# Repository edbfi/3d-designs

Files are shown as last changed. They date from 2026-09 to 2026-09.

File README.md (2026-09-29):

# 3d-designs

My parametric 3D-print designs. Each one is an OpenSCAD source you can customise, plus ready-to-print Bambu Studio projects.

## Designs

| Design | What it is | Path |
|---|---|---|
| Netflix-style lettering | `NETFLIX` and `SERIER` in Netflix-style bent lettering for a school library display: a stand, a plaque and loose wall letters. Built for the Bambu Lab A1 mini (with or without AMS lite) and A2L Combo | [`netflix-lettering`](netflix-lettering) |

## Layout

Every design has its own folder:

```
<design>/
├── README.md            # what it is, which file to print, how to customise
├── <design>.scad        # the parametric source (OpenSCAD Customizer)
├── fonts/               # bundled fonts with their licences, if any
├── print-files/         # ready-to-print Bambu Studio projects, one folder per printer setup
├── templates/           # paper templates, if any
├── docs/                # design notes, build summary, images
└── tools/               # the script that regenerates print-files/ and docs/
```

## Licence

[AGPL-3.0](LICENSE), except bundled fonts, which keep their own licence (see each design's `fonts/`).

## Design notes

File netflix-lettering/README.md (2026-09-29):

# Netflix-style lettering

Two exhibition pieces for a school library, `NETFLIX` and `SERIER`, in Netflix-style bent lettering. Each comes in three designs, and every file is ready to print on a Bambu Lab A1 mini (with or without an AMS lite) or an A2L Combo. Everything is parametric, so a new word, font or size is one setting away.

| | NETFLIX | SERIER |
|---|---|---|
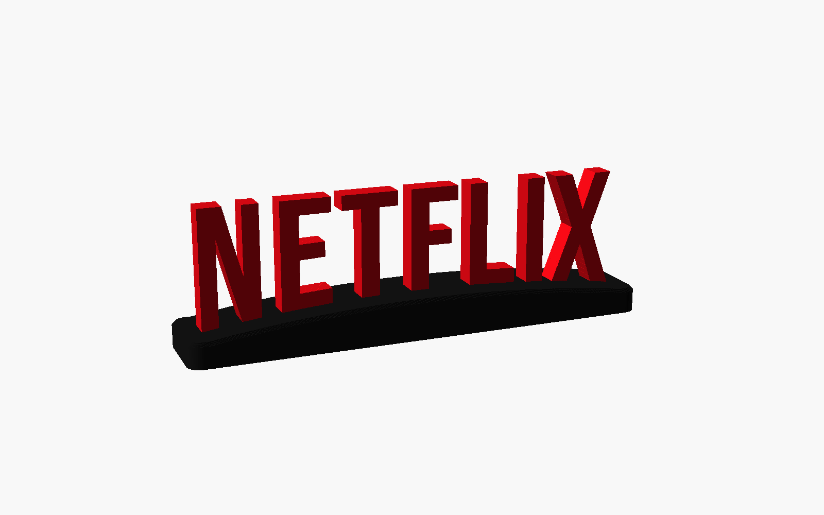
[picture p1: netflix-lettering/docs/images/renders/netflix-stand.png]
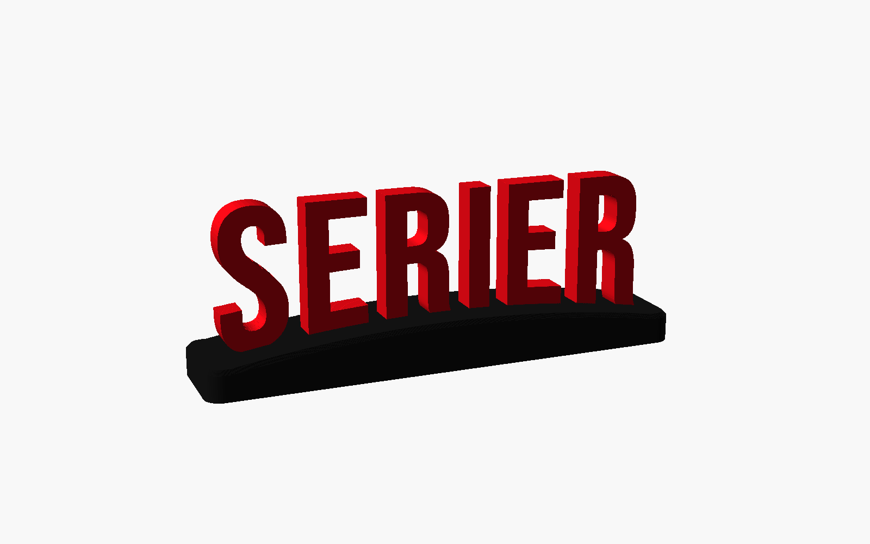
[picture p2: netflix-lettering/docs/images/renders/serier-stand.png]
| **Stand**: red letters on a black plinth that follows the arc |  |  |
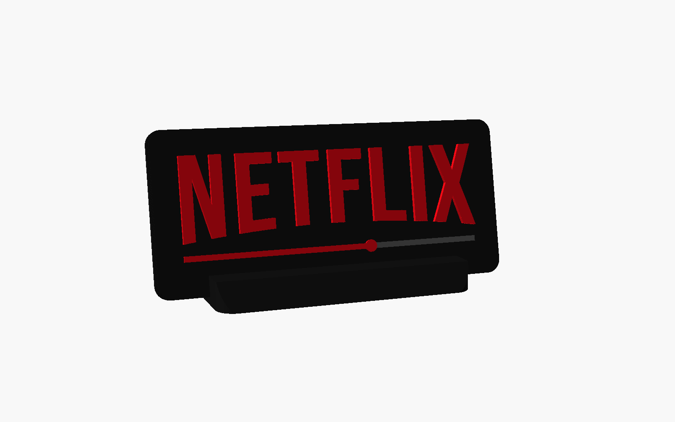
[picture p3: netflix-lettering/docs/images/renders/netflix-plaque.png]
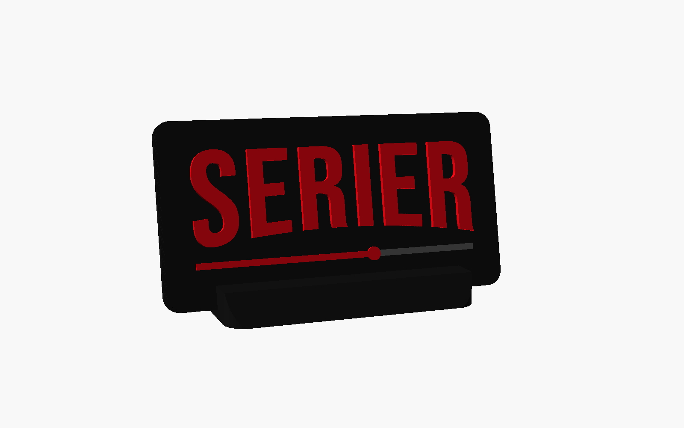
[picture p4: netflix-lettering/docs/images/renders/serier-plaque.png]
| **Plaque**: black screen with raised letters and a Netflix progress bar, in a leaning stand |  |  |
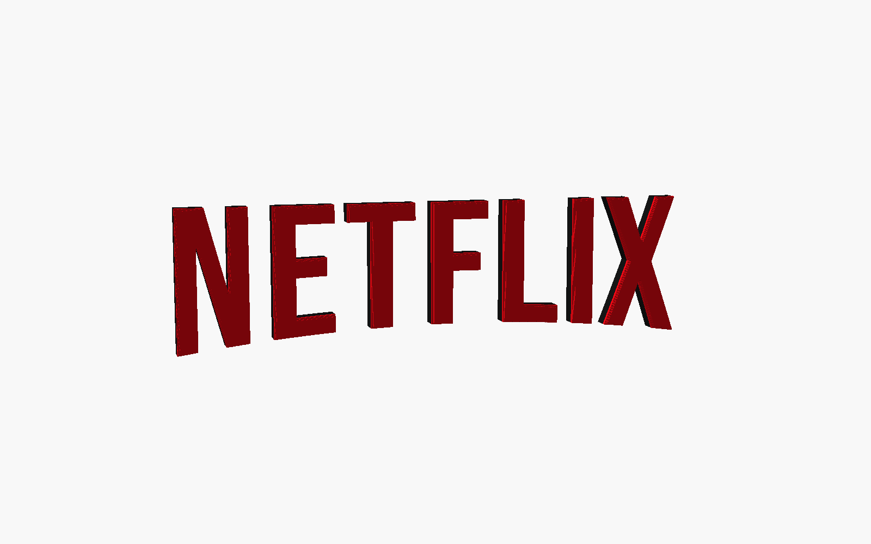
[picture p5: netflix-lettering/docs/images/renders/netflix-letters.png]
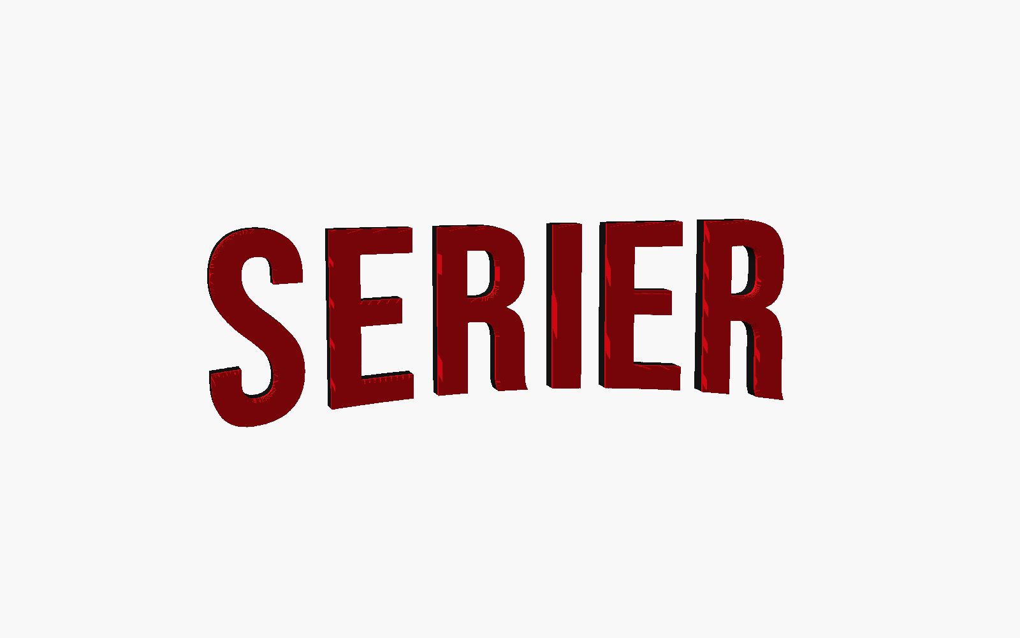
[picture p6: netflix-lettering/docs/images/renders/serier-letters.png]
| **Loose letters**: chunky two-tone letters for a wall or pinboard |  |  |

## Pick a file

Open the `.3mf` in Bambu Studio. The printer, plates, filaments, colours and any filament-swap pauses are already set, and every plate is sliced. For the plates, times and grams of each file, see [`docs/build-summary.md`](docs/build-summary.md).

The files come in three sets, each with all three designs:

- **`single-colour/`**: no AMS; every plate prints in one colour. The colours come from separate parts that go together afterwards. This is the simplest option for the two A1 minis.
- **`colour-swap/`**: no AMS; some plates pause once so you can swap black for red by hand, which gives two-tone parts from one plate.
- **`ams/`**: the AMS lite switches colours by itself, on the A1 mini with an AMS lite or on the A2L Combo (bigger versions).

| Design | Single colour (A1 mini) | Colour swap (A1 mini) | AMS (A1 mini + AMS lite) | AMS (A2L Combo) |
|---|---|---|---|---|
| Stand | [netflix](print-files/single-colour/a1-mini/netflix-stand-single-colour-a1-mini.3mf) · [serier](print-files/single-colour/a1-mini/serier-stand-single-colour-a1-mini.3mf) | [netflix](print-files/colour-swap/a1-mini/netflix-stand-colour-swap-a1-mini.3mf) · [serier](print-files/colour-swap/a1-mini/serier-stand-colour-swap-a1-mini.3mf) | [netflix](print-files/ams/a1-mini/netflix-stand-ams-a1-mini.3mf) · [serier](print-files/ams/a1-mini/serier-stand-ams-a1-mini.3mf) | [netflix](print-files/ams/a2l-combo/netflix-stand-ams-a2l-combo.3mf) · [serier](print-files/ams/a2l-combo/serier-stand-ams-a2l-combo.3mf) |
| Plaque | [netflix](print-files/single-colour/a1-mini/netflix-plaque-single-colour-a1-mini.3mf) · [serier](print-files/single-colour/a1-mini/serier-plaque-single-colour-a1-mini.3mf) | [netflix](print-files/colour-swap/a1-mini/netflix-plaque-colour-swap-a1-mini.3mf) · [serier](print-files/colour-swap/a1-mini/serier-plaque-colour-swap-a1-mini.3mf) | [netflix](print-files/ams/a1-mini/netflix-plaque-ams-a1-mini.3mf) · [serier](print-files/ams/a1-mini/serier-plaque-ams-a1-mini.3mf) | [netflix](print-files/ams/a2l-combo/netflix-plaque-ams-a2l-combo.3mf) · [serier](print-files/ams/a2l-combo/serier-plaque-ams-a2l-combo.3mf) |
| Loose letters | [netflix](print-files/single-colour/a1-mini/netflix-letters-single-colour-a1-mini.3mf) · [serier](print-files/single-colour/a1-mini/serier-letters-single-colour-a1-mini.3mf) | [netflix](print-files/colour-swap/a1-mini/netflix-letters-colour-swap-a1-mini.3mf) · [serier](print-files/colour-swap/a1-mini/serier-letters-colour-swap-a1-mini.3mf) | [netflix](print-files/ams/a1-mini/netflix-letters-ams-a1-mini.3mf) · [serier](print-files/ams/a1-mini/serier-letters-ams-a1-mini.3mf) | [netflix](print-files/ams/a2l-combo/netflix-letters-ams-a2l-combo.3mf) · [serier](print-files/ams/a2l-combo/serier-letters-ams-a2l-combo.3mf) |

Finished sizes (NETFLIX; SERIER is about 15 % narrower):

| Design | A1 mini files | A2L Combo files |
|---|---|---|
| Stand | 167 × 30 mm plinth, 42 mm letters, 51 mm tall | 301 × 50 mm plinth, 76 mm letters, 90 mm tall |
| Plaque | 155 × 69 mm, 36 mm letters | 295 × 126 mm, 70 mm letters |
| Loose letters | 75 mm tall, 294 mm wide on the wall | 120 mm tall, 458 mm wide on the wall |

All files use Bambu PLA Matte, the 0.20 mm Standard profile and the textured PEI plate. Any PLA works; pick a strong red (Netflix red is `#E50914`) and a black or charcoal.

## Printing and assembly

Every no-AMS project has two plates, so both A1 minis can run at once: in Bambu Studio, send plate 1 to one printer and plate 2 to the other. With one printer, print them one after the other.

### Single colour (no AMS)

- **Stand**: plate 1 is the letters, in red, printed face down so the textured plate gives them a crisp front. Plate 2 is the plinth, in black. Push each letter's tab into its pocket; it's a press fit with 0.15 mm clearance per side, and a drop of glue makes it permanent. About 50 min per printer.
- **Plaque**: plate 1 is the red letters and the progress bar's fill as separate pieces, printed face down (about 17 min). Plate 2 is the black plaque with matching pockets, and its stand. Press each red piece into its pocket (0.15 mm clearance; glue optional), then slide the plaque into the stand's leaning slot.
- **Loose letters**: all red, split over two plates.

### Colour swap (no AMS, one manual swap per plate)

- **Stand**: the same two plates as the single-colour set. Change the spool between plates rather than mid-print: the arched plinth has no single layer where black could end, so a one-piece swap isn't possible.
- **Plaque**: plate 1 starts in black and **pauses at 4.2 mm**. On the printer, unload black, load red and resume. The letters and the filled part of the bar come out red; the rest of the bar stays a black groove. Plate 2 is the black stand.
- **Loose letters**: both plates start in black and **pause at 7.2 mm**. Swap to red and resume, which gives black letters with a red face.

### AMS (A1 mini + AMS lite, or the A2L Combo)

One plate, no manual swaps. Load red in the slot for filament 1 and black for filament 2. The plaque also uses grey as filament 3, for the bar's track.

- **Stand**: prints upright in one piece, running along the bed's Y axis so the thin letters are stiff against the moving bed. Bambu's tree supports hold up the arms of E, F and T and snap off their hidden undersides. The model can build [support-fin](https://printfins.com/)-style breakaway fins instead (`stand_fins = true`). Bambu Studio flags model-built supports as a floating cantilever, though, so the files use its own supports.
- **Plaque**: the plaque and its stand print together.
- **Loose letters**: black body with a red face. The AMS changes colour once per plate.

### Hanging the loose letters

Print the matching template from [`templates/`](templates) at 100 % scale (no "fit to page"). The A1 mini ones need A3, or A4 tiled; the A2L ones need tiling. Tape it to the wall, then place each letter on its outline. The line above the letters is the flat top edge; keep it level. Double-sided foam tape or poster putty holds the letters well. The model can also add a back recess for tape or magnet sheet (`letters_mount = "recess"`).

## Customise

Open `netflix-lettering.scad` in [OpenSCAD](https://openscad.org) and show **Window → Customizer**. The main settings:

| Setting | What it does |
|---|---|
| `text_string` | The text. Lowercase is turned into capitals (`force_caps`), and spaces and Norwegian letters work |
| `font_name` | Bebas Neue (default, closest to Netflix), Anton (heavier), League Gothic (narrower), or any installed font |
| `letter_height` | Height of the outer letters in mm; the width follows from the text |
| `arc_depth` | How much shorter the middle letters are (0 = straight, 0.134 = Netflix logo) |
| `letter_spacing`, `stroke_weight` | Tighter or looser spacing; bolder or thinner strokes |
| `design` | `stand`, `plaque` or `letters` |
| `part` | `display` for the coloured preview; the other values output one print part laid out for printing |

Each design has its own group of settings: plinth size, chamfers, letter depth, plaque margins, progress-bar fill, stand tilt, mounting recess and so on. Every setting has a comment in the file.

A full render takes 5–20 s.

To get your own text into Bambu Studio, you have two options:

- **One part at a time**: set `part` (for example `letters` and then `base` for the stand), press F6 and export each as STL.
- **Whole projects**: edit `TEXTS` (and `SIZES` if needed) at the top of [`tools/build.py`](tools/build.py) and run it (see below). You get the same ready-to-print projects as here, for every printer setup.

On **MakerWorld's Parametric Model Maker**, use [`makerworld/netflix-lettering-makerworld.scad`](makerworld/netflix-lettering-makerworld.scad), not the desktop file. It's generated from the desktop file and tested on MakerWorld.

- **Plates:** its 3MF has two plates, one per printer, in the right colours: stand letters and plinth, plaque and its stand, or the loose letters split in two. Set `makerworld_stand = "one piece"` for the upright AMS stand.
- **Fonts:** you get MakerWorld's font picker with 500+ Google Fonts; Bebas Neue is among them.
- **Before printing a MakerWorld 3MF:** switch the plate type to **Textured PEI Plate** in Bambu Studio. MakerWorld defaults to Cool Plate, which heats the bed to only 35 °C.
- **No pauses:** MakerWorld can't add filament-swap pauses, so the plaque and loose letters need an AMS for two colours. For the no-AMS two-colour versions, use the files in `print-files/`.

The desktop file uses no experimental OpenSCAD features, so it runs in the stock Customizer too.

## Rebuilding the print files

```bash
python3 tools/build.py                                   # everything, about 4 minutes
python3 tools/build.py --only serier --only 'a1-mini$'   # a subset
python3 tools/build.py --list                            # all variant keys
```

Needs OpenSCAD (a 2025+ snapshot with the Manifold backend is much faster than 2021.01) and Bambu Studio in `/Applications` (tested with 02.08.02.61). For every variant the script:

1. exports the parts,
2. lays out the plates,
3. builds the project with Bambu Studio's CLI and adds the pauses,
4. slices every plate with the stock Bambu profiles.

It refuses to write a project unless all of these hold:

- no stray mesh slivers,
- the real printer start G-code is present,
- each plate uses the right filament,
- pauses are at the exact layer.

Plate previews, the build summary, templates and renders in `docs/` are regenerated too.

## How the Netflix look is made

The Netflix wordmark is custom lettering, and Netflix Sans isn't free. So this uses **Bebas Neue**, a free font (SIL OFL) whose letter widths match the logo's within about 2 % of the letter height. It is then bent like the logo:

- the top edge stays flat;
- the bottom edge follows a parabola, so the middle letters are 13.4 % shorter than the outer ones.

Those numbers, and letter spacing 1.08, were measured and fitted against the real logo. For the measurements, the font comparison and the geometry tricks that keep the model customisable without experimental OpenSCAD features, see [`docs/design-notes.md`](docs/design-notes.md).

## Files

```
netflix-lettering/
├── netflix-lettering.scad      # the parametric model
├── fonts/                      # Bebas Neue, Anton, League Gothic + their OFL licences
├── print-files/
│   ├── single-colour/a1-mini/  # no AMS, one colour per plate, parts go together
│   ├── colour-swap/a1-mini/    # no AMS, a pause for a manual filament swap
│   └── ams/                    # AMS lite: a1-mini/ and a2l-combo/ (bigger versions)
├── makerworld/                 # MakerWorld Parametric Model Maker edition (generated)
├── templates/                  # 1:1 wall templates for the loose letters (SVG)
├── docs/
│   ├── design-notes.md         # research, measurements, techniques
│   ├── build-summary.md        # every project: plates, times, grams (generated)
│   └── images/                 # renders and Bambu plate previews (generated)
└── tools/build.py              # regenerates print-files/, templates/ and docs/
```

## Licence and trademarks

The model, build script and print files are [AGPL-3.0](../LICENSE). The MakerWorld listing ("Streaming-style bent lettering (customizable)", a draft for now) offers the MakerWorld edition under [CC BY-SA 4.0](https://creativecommons.org/licenses/by-sa/4.0/), the closest Creative Commons match to the AGPL's share-alike terms. The fonts in `fonts/` are under the SIL Open Font License 1.1 and belong to their authors (see the `OFL-*.txt` files).

Netflix is a trademark of Netflix, Inc. This is an independent, fan-made lookalike for a school library display. It is not affiliated with or endorsed by Netflix, and it contains no Netflix artwork: the lettering is a free font bent to a similar shape.

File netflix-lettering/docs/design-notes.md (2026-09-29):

# Design notes

How the Netflix look was measured and rebuilt, and the techniques that keep the model fully parametric in plain OpenSCAD.

## Measuring the Netflix wordmark

The 2015 Netflix wordmark (the Wikimedia Commons SVG, used only as a local reference and not included in this repo) was rasterised and measured column by column:

| Property | Netflix logo |
|---|---|
| Top edge | Flat: every letter starts at the same line |
| Bottom edge | Arc, lowest at the outer letters and highest in the middle |
| Middle letters vs. outer letters | 13.4 % shorter |
| Arc shape | A parabola: at 10/20/30/40 % across, the bottom sits at 0.951/0.915/0.888/0.874 of the full height; a parabola with depth 0.134 gives 0.952/0.914/0.887/0.873 |
| Word width | 3.70 × the outer letter height |
| Stem width | 0.15–0.17 × letter height |
| Letter widths (× height) | N 0.51, E 0.43, T 0.48, F 0.44, L 0.42, I 0.15, X 0.57 |
| Gap between letters | About 0.10 × height |

The top edge is flat and only the bottom curves. That is what makes it read as "Netflix", and a first attempt that curved both edges looked wrong.

## Choosing the font

The Netflix lettering is custom, and Netflix Sans is proprietary. Free condensed fonts, measured with OpenSCAD's `textmetrics` (widths as a fraction of cap height):

| Font | Stem | N | E | T | F | L | I | X | Word (spacing 1) |
|---|---|---|---|---|---|---|---|---|---|
| **Netflix logo** | 0.15–0.17 | 0.51 | 0.43 | 0.48 | 0.44 | 0.42 | 0.15 | 0.57 | 3.70 |
| **Bebas Neue** | 0.16 | 0.49 | 0.43 | 0.49 | 0.42 | 0.42 | 0.16 | 0.55 | 3.41 |
| Anton | 0.19 | 0.49 | 0.41 | 0.44 | 0.40 | 0.41 | 0.19 | 0.53 | 3.21 |
| League Gothic | 0.15 | 0.43 | 0.34 | 0.42 | 0.35 | 0.34 | 0.15 | 0.47 | 2.93 |

Bebas Neue matches every letter within about 0.02 of the letter height. The only real difference is spacing. Sweeping `letter_spacing`, `arc_depth` and `stroke_weight` against the rasterised logo (overlap measured as intersection over union) gave the defaults:

| letter_spacing | 1.00 | 1.04 | 1.06 | **1.08** | 1.10 | 1.12 |
|---|---|---|---|---|---|---|
| overlap with the logo | 0.41 | 0.52 | 0.69 | **0.83** | 0.73 | 0.55 |

`arc_depth` 0.134 (the measured value) scored best. Any extra stroke weight made it worse. The rest of the gap to a perfect overlap comes from the logo's custom N and X diagonals.

## Bending text in plain OpenSCAD

OpenSCAD can't warp geometry, so `warp2d` cuts the word into vertical strips and scales each one vertically about the top edge, by `1 − arc_depth · (1 − u²)` (u = −1…1 across the word). Neighbouring strips abut exactly. The number of strips follows from the letter height and arc depth, so the step between two strips along the bottom edge stays around `bend_step` = 0.1 mm, well below what a 0.4 mm nozzle can show. That's about 240 strips for 42 mm letters and the 800-strip cap at 120 mm. Straight text (`arc_depth` = 0) isn't cut at all.

Everything else that has to meet the lettering is bent with the same strips, so the surfaces match to within 0.01 mm:

- the plinth's arched top,
- the region under the arc used for tabs and pockets.

The arc is anchored to the text's **baseline**, not its lowest point. Round letters (S, O) dip slightly below the baseline, and anchoring to them would leave the flat letters floating above the plinth. The dip is trimmed from the one-piece letters so the two colours never overlap in the slicer.

## Parametric without measuring text

A MakerWorld-style model must react to any text, font and size, but `textmetrics` is experimental: it's off by default, and MakerWorld can't be relied on to have it. So the `.scad` never measures the text numerically. Instead:

- **Bounding boxes** come from hulls of copies pushed ±10 km along one axis (`bbox2d`, `xband2d`).
- **Normalising width**: the word is resized to exactly 100 units wide so the bend's u-coordinate is known. Sub-shapes (such as one letter's column) ride along with a far-away copy of the whole word's box, so they get the word's scale factor, not their own (`to_norm`).
- **Final size**: a box three times the letter height rides along 2000 units to the right, so every shape gets the letters' scale. It's then cut off again (`to_final`).
- **Centring**: the font's side bearings would push the word off-centre and make the arc lopsided. A Minkowski sum with a tiny square at minus the ink centre fixes that. The square is built from the ink box's corners scaled by −½ (`centre_shift2d`).
- **Proportional positions**: the progress bar's fill end is the word's right edge scaled by `2f − 1`.
- **Cleanup**: a morphological opening (`offset(r = 0.02) offset(r = −0.02)`) drops scraps thinner than 0.04 mm that coincident edges can leave. The stepped chamfers use round-join insets, because mitred insets turn microscopic notches into long spikes.

The bend instantiates its child once per strip, so that child is kept tiny (bare text or a box). An early version that passed richer subtrees through it took 1 min 40 s per render.

Three more habits keep a full render at 0.3–2 s (stand 1.3 s, plaque 0.3 s, loose letters 2.1 s at 42 mm):

- Offsets use bevelled joins (`chamfer = true`). Round joins put an arc on every strip corner.
- The word's x-range comes from the unbent box, because the bend only moves points vertically.
- The loose-letters preview extrudes the whole word at once instead of letter by letter.

## MakerWorld's Parametric Model Maker

Tested on MakerWorld with the logged-in account (unpublished):

- **Backend:** MakerWorld runs OpenSCAD with the Manifold backend and a render limit of about 10 s. The first upload timed out at 11 s local render time; after the speedups above it generates in about 13–20 s wall-clock, including MakerWorld's own overhead.
- **Plates:** MakerWorld builds a multi-plate, multi-colour 3MF from `mw_plate_N()` modules and `color()`, and previews `mw_assembly_view()`. It also adds any top-level geometry to every plate. So `tools/build.py` generates `makerworld/netflix-lettering-makerworld.scad` with the desktop output switched off. That edition also drops the local font includes, marks `font_name` with `// font` (MakerWorld's picker of 500+ Google Fonts; Bebas Neue is among them) and hides the desktop-only settings. The build checks that the edition has no top-level geometry and that every plate renders.
- **What its 3MF gets right:** the downloaded stand project has two plates, the red letters on filament 1 and the black plinth on filament 2. It carries the fully resolved A1 mini profile: real start G-code, 0.20 mm Standard, PLA Basic. Sliced, it takes 38 + 45 min, the same as our own files.
- **What it gets wrong:** the bed type is Cool Plate, so the bed heats to 35 °C, and supports are on (no supports actually get generated for these parts). Change the plate type to Textured PEI Plate in Bambu Studio before printing. MakerWorld can only preset profile options from a model's upload/edit page.
- **What it can't do:** there are no filament-swap pauses, so the no-AMS plaque and loose letters come out single-colour unless you print on an AMS printer or add the pause in Bambu Studio yourself. Multi-plate scripts can't offer STL download.

## Printability decisions

- **Stand, two-part (no AMS)**: letters print face down, so the textured PEI plate gives the visible face. Tabs follow each letter's bent bottom edge into matching pockets, with 0.15 mm clearance per side (0.146 mm measured).
- **Stand, one piece (AMS)**: letters print upright. The horizontal arms of E, F and T overhang 7–13 mm, so the project turns on tree supports. The word is turned to run along Y: on a bed-slinger, the thin letters then see the bed's motion along their stiff direction.
- **Breakaway fins (option)**: `stand_fins` builds supports into the model, in the spirit of [Support Fins](https://printfins.com/). printfins.com itself is a browser tool with manual orientation and no command-line interface, so the build can't call it.
  - *Where fins go:* a 1 mm skin is taken under every downward-facing edge and opened with r = 0.35 mm, which keeps only the overhangs flatter than 45°.
  - *Shape:* the region under those overhangs becomes twin 0.8 mm walls with one-layer rungs every 5 mm. They stand on the plinth or on a lower arm and stop 0.25 mm short of the letters, above and beside.
  - *Why off by default:* Bambu Studio can't see model-built supports and reports a "floating cantilever", while its own tree supports are warning-free here. The build fails on either warning, so the files use tree supports.
- **Three print-file sets**: `ams` (the AMS switches colours), `single-colour` (one colour per plate; colours come from separate parts) and `colour-swap` (a pause for a hand swap).
  - *Stand:* the arched plinth has no single layer where black could end, so the stand can't be swapped mid-print. Its colour-swap version is the two-part stand, with the spool changed between plates.
- **Plaque (single colour)**: the red letters and bar fill print face down as separate pieces. They press into 1.2 mm pockets in the black plaque, with 0.15 mm clearance per side. The pockets leave 2.8 mm of plaque below; the pieces stand 2 mm (letters) and 1 mm (bar) proud, like the other versions.
- **Plaque (colour swap)**: one filament swap. Black is used up to the plaque's top face (4.0 mm), and a pause runs at the start of the 4.2 mm layer. The progress bar's track is a groove in the plaque; the red fill and scrubber dot rise out of it, so the no-AMS version still reads as a two-colour bar.
- **Loose letters**: printed face up, with a 45° chamfer drawn in 0.2 mm steps (one per layer). The face is the top 3 mm, so a two-tone print needs only one colour change per plate. Letters are split over two plates by width, so two printers share the work.
- **Plate layout**: AMS plates keep a 45 × 55 mm corner free for the prime tower.

## Verification

Checked for these designs:

- **Overlap with the Netflix logo**: 83 % (above).
- **One-piece contact**: letters meet the plinth with 0.008 mm³ of overlap. Vertical rays through every letter run solid into the plinth.
- **Two-part fit**: letter tabs clear the plinth pockets by 0.146 mm.
- **Every build variant**:
  - no slivers in any part,
  - real Bambu start G-code (textured-plate bed temperature, A1 mini/A2L calibration routine),
  - each plate on the intended filament,
  - pauses exactly at the intended layer,
  - no slicer warnings.
- **Customisation stress test**: lowercase text, a space (`LES MER`), Norwegian `Ø`, Anton and League Gothic, `arc_depth` 0 and 0.25, and letter heights from 36 to 120 mm.

## Known limits

- `letter_height` runs from the baseline to the top of the text, so a round top overshoot (S, O) counts in it. Flat-topped outer letters of a word that contains round letters are about 1.5 % shorter (0.6 mm at 42 mm).
- In the Customizer, check that the text fits your bed. The build script checks the fit and splits the loose letters over extra plates automatically.
- `Impact` is only there if it's installed on the computer (it is on macOS and Windows). On MakerWorld, stick to Google Fonts.
- The upright one-piece stand needs supports. For the cleanest letter faces on an AMS printer, you can still print the two-part A1 mini version.

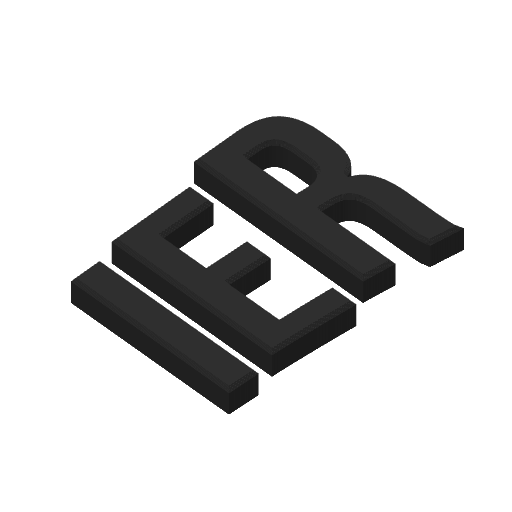
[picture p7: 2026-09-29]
netflix-lettering/docs/images/plates/serier-letters-colour-swap-a1-mini-plate-2.png

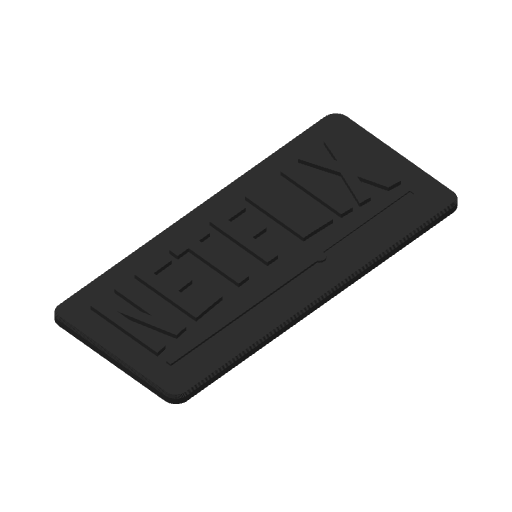
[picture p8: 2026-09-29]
netflix-lettering/docs/images/plates/netflix-plaque-colour-swap-a1-mini-plate-1.png

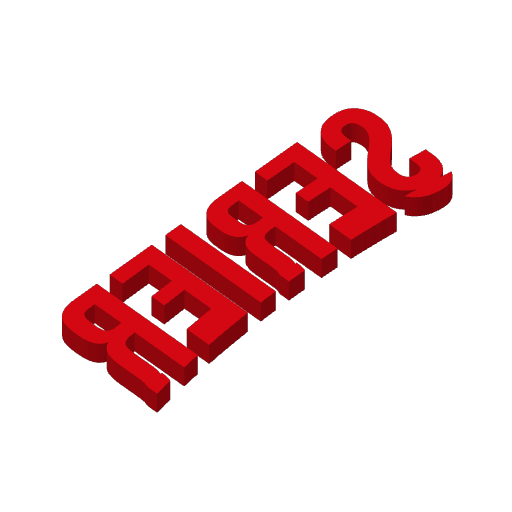
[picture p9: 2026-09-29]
netflix-lettering/docs/images/plates/serier-stand-single-colour-a1-mini-plate-1.png

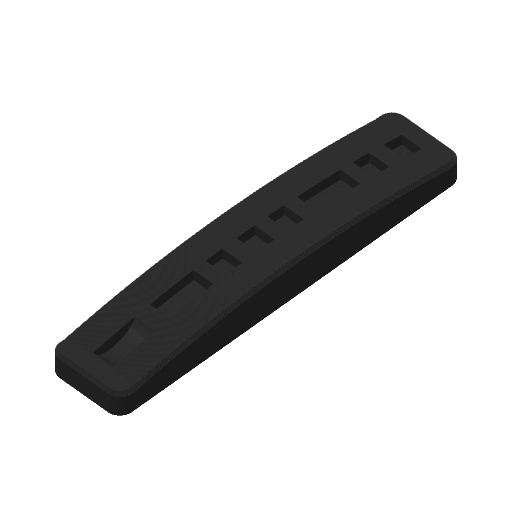
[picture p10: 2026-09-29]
netflix-lettering/docs/images/plates/serier-stand-colour-swap-a1-mini-plate-2.png

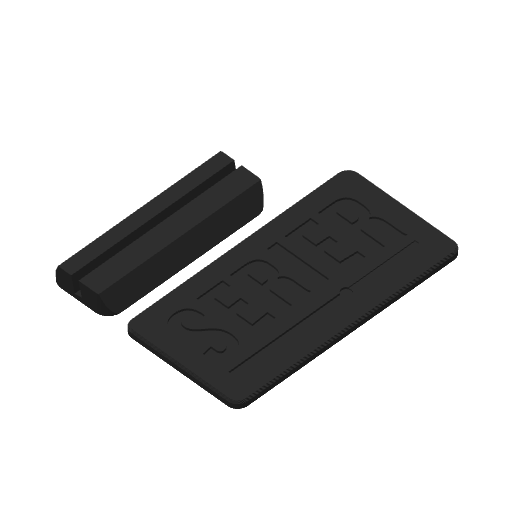
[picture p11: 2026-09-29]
netflix-lettering/docs/images/plates/serier-plaque-single-colour-a1-mini-plate-2.png

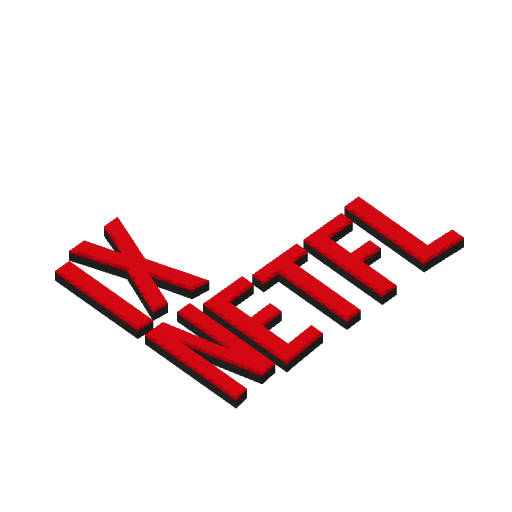
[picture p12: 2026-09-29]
netflix-lettering/docs/images/plates/netflix-letters-ams-a2l-combo-plate-1.png

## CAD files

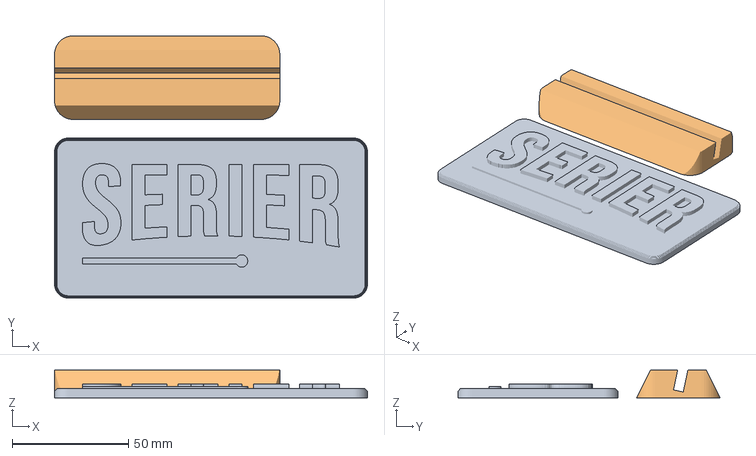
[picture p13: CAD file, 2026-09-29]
netflix-lettering/print-files/ams/a1-mini/serier-plaque-ams-a1-mini.3mf
134.9 x 113.0 x 12.0 mm
SERIER Plaque
SERIER Plaque stand

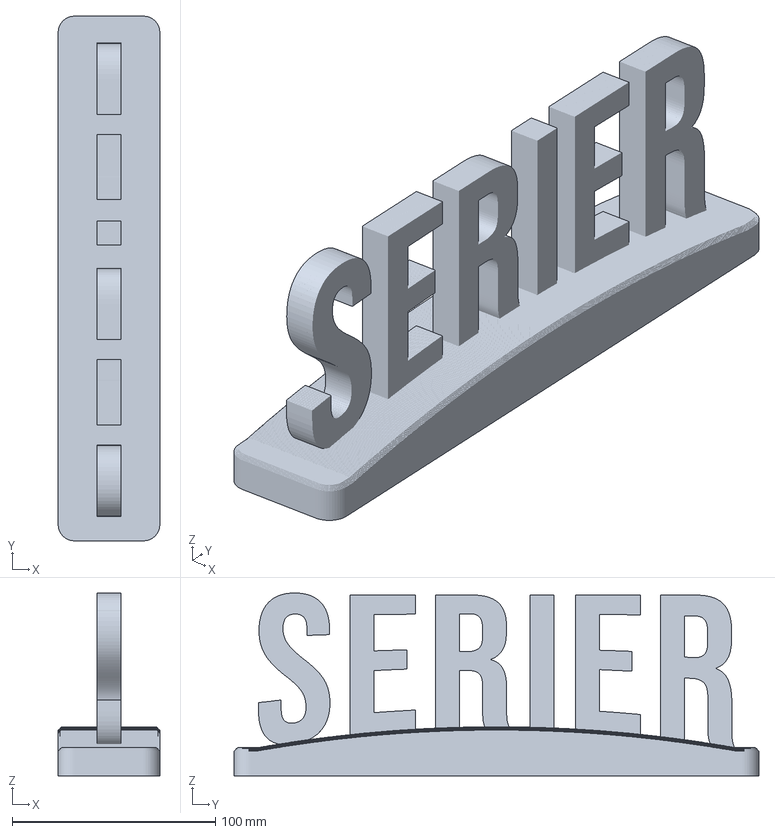
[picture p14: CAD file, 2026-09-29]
netflix-lettering/print-files/ams/a2l-combo/serier-stand-ams-a2l-combo.3mf
50.0 x 258.1 x 90.0 mm

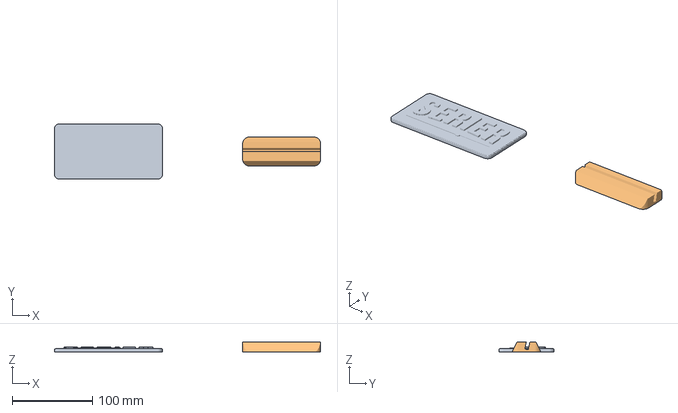
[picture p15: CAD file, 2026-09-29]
netflix-lettering/print-files/colour-swap/a1-mini/serier-plaque-colour-swap-a1-mini.3mf
332.0 x 69.0 x 12.0 mm
SERIER Plaque
SERIER Plaque stand

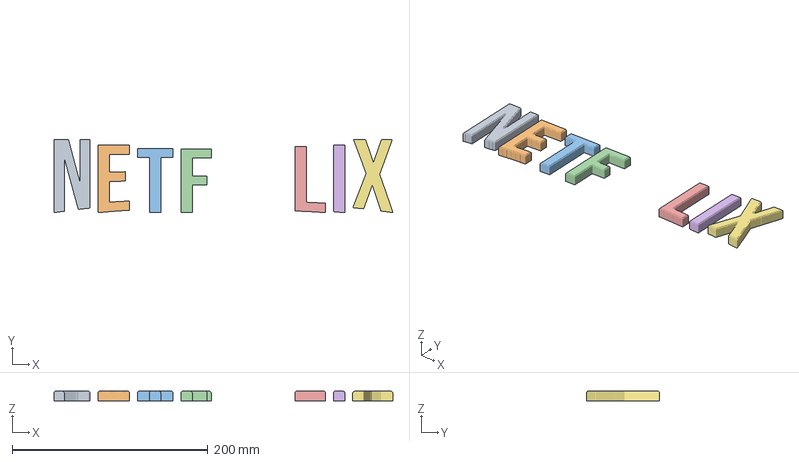
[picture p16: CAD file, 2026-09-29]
netflix-lettering/print-files/single-colour/a1-mini/netflix-letters-single-colour-a1-mini.3mf
346.5 x 75.0 x 10.0 mm
NETFLIX Letter 1 N
NETFLIX Letter 2 E
NETFLIX Letter 3 T
NETFLIX Letter 4 F
NETFLIX Letter 5 L
NETFLIX Letter 6 I
NETFLIX Letter 7 X

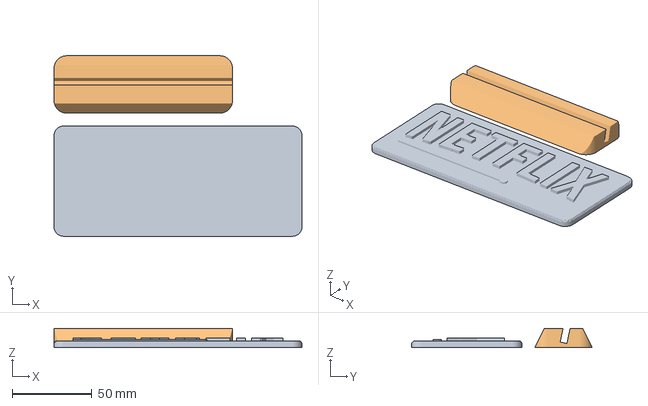
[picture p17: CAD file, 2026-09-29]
netflix-lettering/print-files/ams/a1-mini/netflix-plaque-ams-a1-mini.3mf
155.2 x 113.0 x 12.0 mm
NETFLIX Plaque
NETFLIX Plaque stand

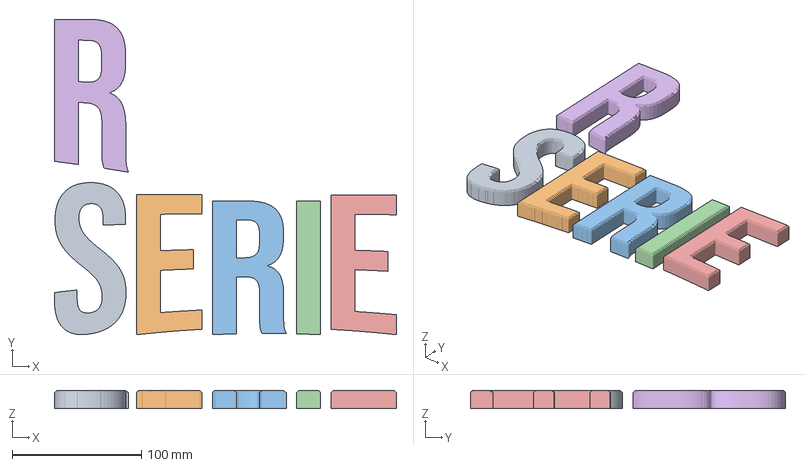
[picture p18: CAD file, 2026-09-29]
netflix-lettering/print-files/ams/a2l-combo/serier-letters-ams-a2l-combo.3mf
264.8 x 244.2 x 14.0 mm
SERIER Letter 1 S
SERIER Letter 2 E
SERIER Letter 3 R
SERIER Letter 4 I
SERIER Letter 5 E
SERIER Letter 6 R

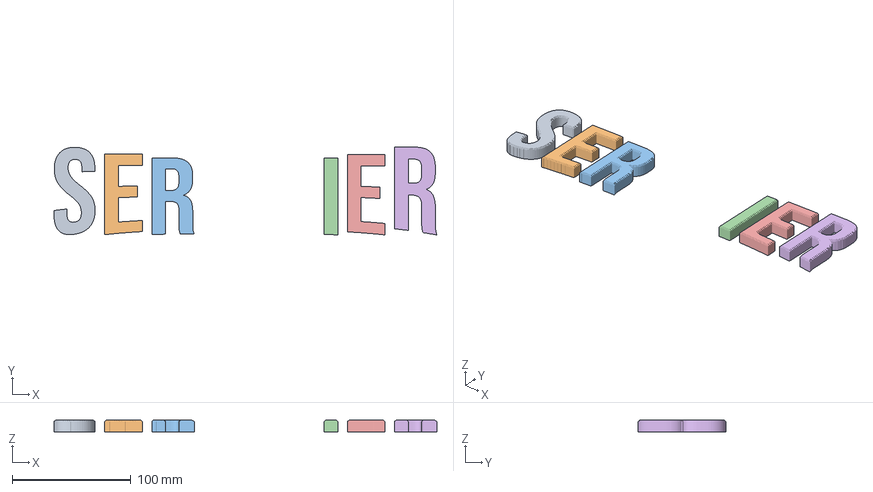
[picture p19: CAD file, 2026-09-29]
netflix-lettering/print-files/colour-swap/a1-mini/serier-letters-colour-swap-a1-mini.3mf
322.7 x 74.0 x 10.0 mm
SERIER Letter 1 S
SERIER Letter 2 E
SERIER Letter 3 R
SERIER Letter 4 I
SERIER Letter 5 E
SERIER Letter 6 R

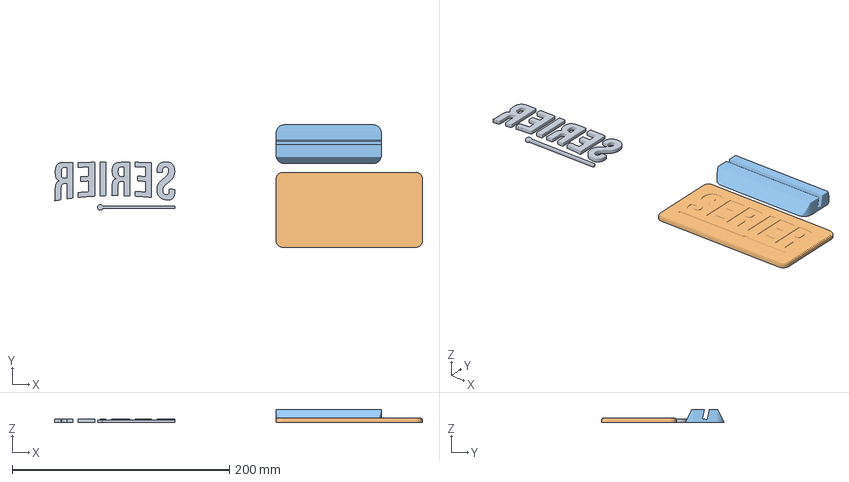
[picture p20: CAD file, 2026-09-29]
netflix-lettering/print-files/single-colour/a1-mini/serier-plaque-single-colour-a1-mini.3mf
338.9 x 113.0 x 12.0 mm
SERIER Red pieces
SERIER Plaque
SERIER Plaque stand

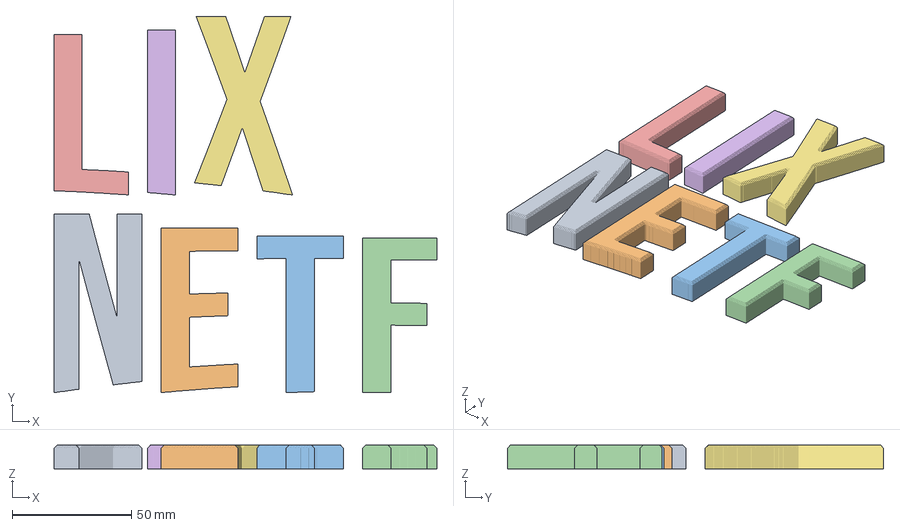
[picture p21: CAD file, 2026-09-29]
netflix-lettering/print-files/ams/a1-mini/netflix-letters-ams-a1-mini.3mf
160.8 x 158.0 x 10.0 mm
NETFLIX Letter 1 N
NETFLIX Letter 2 E
NETFLIX Letter 3 T
NETFLIX Letter 4 F
NETFLIX Letter 5 L
NETFLIX Letter 6 I
NETFLIX Letter 7 X

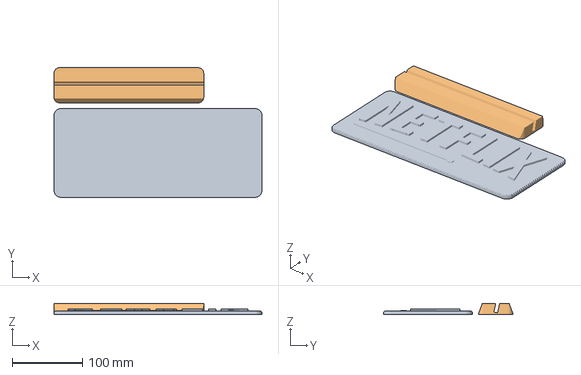
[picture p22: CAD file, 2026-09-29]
netflix-lettering/print-files/ams/a2l-combo/netflix-plaque-ams-a2l-combo.3mf
295.1 x 184.0 x 16.0 mm
NETFLIX Plaque
NETFLIX Plaque stand

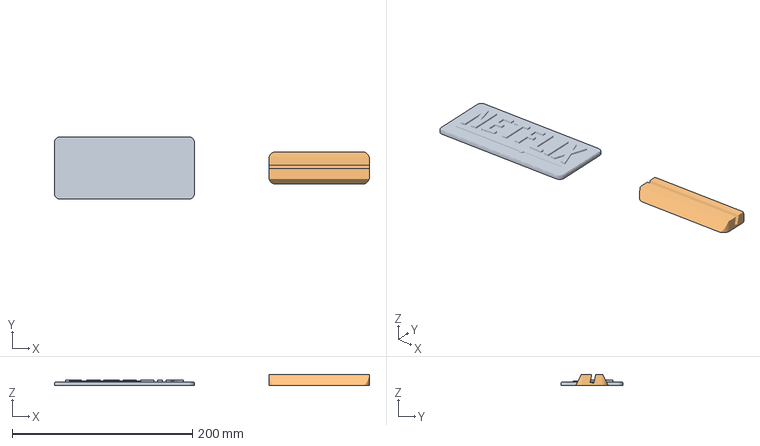
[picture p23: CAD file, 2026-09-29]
netflix-lettering/print-files/colour-swap/a1-mini/netflix-plaque-colour-swap-a1-mini.3mf
349.5 x 69.0 x 12.0 mm
NETFLIX Plaque
NETFLIX Plaque stand

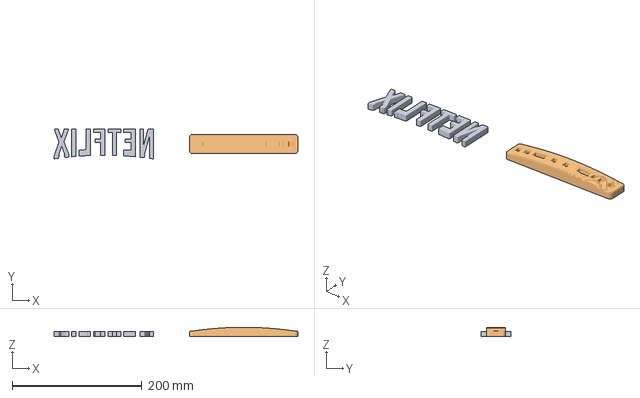
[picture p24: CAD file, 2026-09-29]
netflix-lettering/print-files/single-colour/a1-mini/netflix-stand-single-colour-a1-mini.3mf
376.1 x 46.0 x 14.6 mm
NETFLIX Letters
NETFLIX Plinth

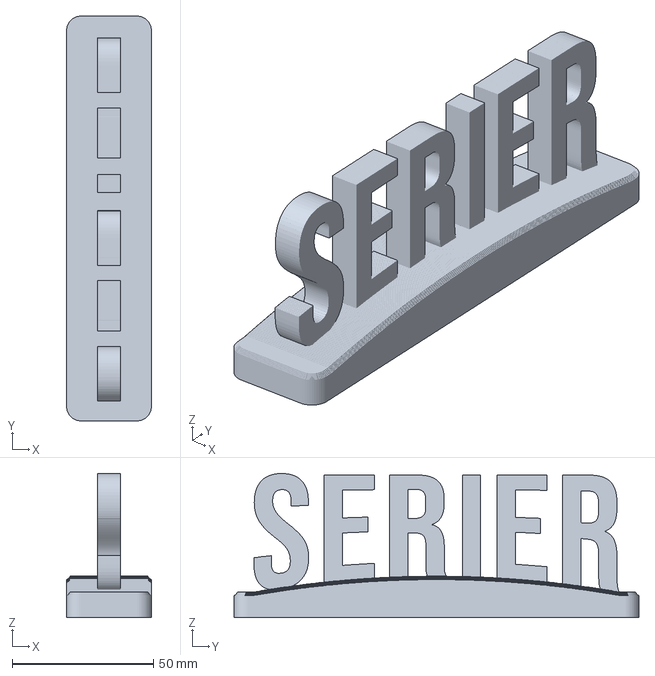
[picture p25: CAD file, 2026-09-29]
netflix-lettering/print-files/ams/a1-mini/serier-stand-ams-a1-mini.3mf
30.0 x 143.3 x 51.0 mm

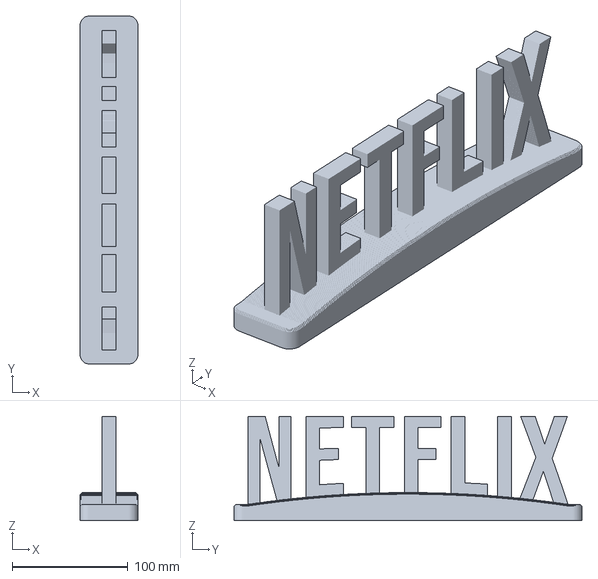
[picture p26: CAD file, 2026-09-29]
netflix-lettering/print-files/ams/a2l-combo/netflix-stand-ams-a2l-combo.3mf
50.0 x 301.0 x 90.0 mm

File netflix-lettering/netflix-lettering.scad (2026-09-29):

// Netflix-style lettering display (parametric, OpenSCAD Customizer / MakerWorld style)
//
// Three designs share one lettering core:
//   "stand"   red letters standing on a black plinth whose top follows the arc
//   "plaque"  black screen-style plaque, raised red letters, Netflix progress bar, ledge stand
//   "letters" loose chunky letters for a wall, pinboard or shelf
//
// Units mm, Z up. Display datum: centred in X and Y on the text, base at Z = 0.
// Print parts ("part" = anything except "display") sit on Z = 0 in print pose: flat,
// except the one-piece stand parts, which print upright as displayed.
//
// The lettering is a free font (Bebas Neue, SIL OFL) bent like the Netflix wordmark:
// flat top edge, bottom edge on a parabolic arc, so the middle letters are shorter
// than the outer ones. Measured on the Netflix logo: middle letters 13.4 % shorter,
// word 3.70 x its height. Bebas Neue's letter widths match the logo's within about 2 %
// of the letter height; letter_spacing = 1.08 gives the best overlap (83 %) with it.
//
// No experimental features are used: text size is never measured numerically.
// Everything that depends on the text width is derived from the geometry itself
// (bounding bands and resize anchors), so any text, font or size just works.

use <fonts/BebasNeue-Regular.ttf>
use <fonts/Anton-Regular.ttf>
use <fonts/LeagueGothic.ttf>

/* [Text] */
// Text to show
text_string = "NETFLIX";
// Font (Bebas Neue matches the Netflix letter widths best; Google fonts also work on MakerWorld)
font_name = "Bebas Neue"; // [Bebas Neue, Anton, League Gothic, Impact]
// Turn the text into capitals
force_caps = true;

/* [Netflix look] */
// How much shorter the middle letters are than the outer ones (0 = straight; Netflix logo = 0.134)
arc_depth = 0.134; // [0:0.002:0.3]
// Letter spacing factor (1 = font default; 1.08 gives the Netflix word proportions with Bebas Neue)
letter_spacing = 1.08; // [0.8:0.01:1.4]
// Extra stroke weight in mm (0 = font as drawn; positive = bolder)
stroke_weight = 0; // [-0.5:0.05:1.5]

/* [Size] */
// Height of the outermost letters (baseline to top) in mm; the width follows from the text
letter_height = 42; // [15:1:150]

/* [Design] */
// Which display to build
design = "stand"; // [stand, plaque, letters]
// What to output: "display" = coloured preview; the rest are print parts laid flat
part = "display"; // [display, letters, base, onepiece_letters, onepiece_base, onepiece_fins, plaque_body, plaque_red, plaque_track, plaque_stand, plaque_body_inlay, plaque_inlays, letter, letter_face, letter_body, template]
// Which letter for the single-letter parts (0 = first)
letter_index = 0; // [0:1:30]

/* [Stand] */
// Letter thickness, front to back
stand_letter_depth = 8; // [3:0.5:20]
// Plinth height under the outer letters
stand_base_height = 9; // [4:0.5:30]
// Plinth depth, front to back
stand_base_depth = 30; // [10:1:80]
// Plinth overhang past the first and last letter
stand_base_margin = 7; // [0:0.5:30]
// Plinth corner radius (plan view)
stand_base_radius = 5; // [0:0.5:20]
// Chamfer on the plinth's top edges
stand_base_chamfer = 1.2; // [0:0.2:4]
// How far the letter tabs reach into the plinth (two-part build)
stand_tab_depth = 4; // [1:0.5:10]
// Letter position front to back on the plinth (0 = centred, negative = towards the front)
stand_letter_offset = 0; // [-20:0.5:20]
// One-piece upright print: breakaway fins under flat overhangs (arms of E, F, T). Off by default:
// slicer tree supports are proven here, and Bambu Studio warns about model-built supports.
stand_fins = false;
// Fin wall thickness
stand_fin_thickness = 0.8; // [0.4:0.1:2]
// Air gap between fins and letters (about one layer)
stand_fin_gap = 0.25; // [0.1:0.05:0.6]

/* [Plaque] */
// Plaque thickness (black body)
plaque_thickness = 4; // [2:0.2:10]
// Height of the raised letters above the plaque
plaque_relief = 2; // [0.6:0.2:6]
// Border left and right of the text
plaque_margin_x = 12; // [3:0.5:40]
// Border above the text
plaque_margin_top = 11; // [3:0.5:40]
// Border below the text (holds the progress bar and the part hidden in the stand)
plaque_margin_bottom = 22; // [6:0.5:60]
// Distance from the lowest letter to the progress bar's centre line
plaque_bar_gap = 6; // [2:0.5:30]
// Corner radius
plaque_radius = 6; // [0:0.5:30]
// Chamfer on the top edge
plaque_chamfer = 1; // [0:0.2:4]
// Show the Netflix progress bar under the text
plaque_progress_bar = true;
// How far the bar is filled (0..1)
plaque_progress = 0.62; // [0:0.01:1]
// Bar thickness (in the plaque plane)
plaque_bar_width = 2.4; // [1:0.1:6]
// Depth of the bar's track groove
plaque_track_depth = 0.6; // [0.2:0.2:2]
// Height of the red bar fill above the plaque face
plaque_bar_relief = 1; // [0.2:0.2:4]
// Single-colour version: how deep the separate red letters and bar sit in their pockets
plaque_inlay_depth = 1.2; // [0.6:0.2:3]
// Lean of the plaque in its stand (degrees back from vertical)
plaque_tilt = 12; // [0:1:30]
// Stand length as a fraction of the plaque width
plaque_stand_fraction = 0.72; // [0.3:0.01:1]
// Stand height
plaque_stand_height = 12; // [6:0.5:40]
// Stand depth front to back
plaque_stand_depth = 36; // [15:1:80]

/* [Loose letters] */
// Letter thickness
letters_depth = 10; // [3:0.5:30]
// Front edge chamfer (0 = none)
letters_chamfer = 1.2; // [0:0.2:4]
// Red face thickness in the two-colour version (the rest is the black body)
letters_face_depth = 3; // [0.6:0.2:10]
// Flatten each letter's bottom so it can stand on a shelf
letters_flat_bottom = false;
// Back: "none" or a "recess" for tape, putty or magnet sheet
letters_mount = "none"; // [none, recess]
// Recess depth and wall thickness
letters_recess_depth = 3; // [1:0.5:10]
letters_recess_wall = 2.4; // [1.2:0.2:6]

/* [Fit and print] */
// Clearance per side for push-fit joints
clearance = 0.15; // [0:0.05:0.5]
// Layer height the stepped chamfers are drawn for
layer_height = 0.2; // [0.08:0.02:0.32]
// Turn print parts about Z (e.g. 90 so tall letters run along a bed-slinger's Y axis)
print_rotate = 0; // [0:90:270]

/* [Colours] */
color_letters = "#E50914"; // color
color_base    = "#141414"; // color
color_track   = "#5A5A5A"; // color

/* [MakerWorld] */
// Stand plates in MakerWorld's 3MF: two parts to press together (any printer), or one upright multi-colour piece (AMS)
makerworld_stand = "two parts"; // [two parts, one piece]

/* [Hidden] */
desktop_output = true;  // false in the MakerWorld edition
$fn = 48;
eps = 0.01;          // overlap for coplanar booleans
BIG = 1e4;           // "infinity" for bounding bands
NORM_W = 100;        // normalised word width used while bending
// Bend resolution: enough vertical strips that the step between neighbours along the
// bottom edge stays under bend_step (mm). Straight text (arc_depth = 0) needs none.
bend_step = 0.1;
warp_strips = min(800, max(60, ceil(4.2 * letter_height * arc_depth / bend_step)));
H = letter_height;

txt = force_caps ? upper(text_string) : text_string;
n_letters = len(txt);

assert(n_letters > 0, "text_string is empty");
assert(arc_depth >= 0 && arc_depth < 0.5, "arc_depth must be in [0, 0.5)");
assert(letter_index >= 0 && letter_index < n_letters, "letter_index is past the end of the text");
assert(stand_tab_depth < stand_base_height, "stand_tab_depth must be less than stand_base_height");
assert(stand_base_height < 0.85 * letter_height && plaque_margin_bottom < 0.85 * letter_height, "base height and plaque bottom margin must stay under 0.85 x letter_height");
assert(letters_face_depth < letters_depth, "letters_face_depth must be less than letters_depth");
assert(plaque_inlay_depth < plaque_thickness - 0.8, "plaque_inlay_depth must leave at least 0.8 mm of plaque under the pockets");
assert(plaque_margin_bottom - plaque_bar_gap - plaque_bar_width > (plaque_stand_height - 3) / cos(plaque_tilt) + 1,
       "progress bar would be hidden by the stand: raise plaque_margin_bottom or lower plaque_stand_height");
echo(str("Text '", txt, "', font ", font_name, ", outer letters ", H, " mm, design ", design, ", part ", part));

// ------------------------------------------------------------------ functions

function upper(s) = chr([for (c = s) let(o = ord(c))
    (o >= 97 && o <= 122) || (o >= 224 && o <= 254 && o != 247) ? o - 32 : o]);

function prefix(s, n) = n <= 0 ? "" : chr([for (k = [0 : n - 1]) ord(s[k])]);

// Vertical scale at normalised position u in [-1, 1]: 1 at the ends, 1 - arc_depth in the middle.
function arc_scale(u) = let(v = max(-1, min(1, u))) 1 - arc_depth * (1 - v * v);

// ------------------------------------------------------------------ 2D helpers

// Bounding rectangle of 2D children.
module bbox2d() {
    intersection() {
        hull() { translate([0,  BIG]) children(); translate([0, -BIG]) children(); }
        hull() { translate([ BIG, 0]) children(); translate([-BIG, 0]) children(); }
    }
}
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

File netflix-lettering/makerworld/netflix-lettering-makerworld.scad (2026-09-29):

// MakerWorld Parametric Model Maker edition. GENERATED from ../netflix-lettering.scad by
// tools/build.py: edit the source, not this file. Output comes from mw_plate_1/2 only.

// Netflix-style lettering display (parametric, OpenSCAD Customizer / MakerWorld style)
//
// Three designs share one lettering core:
//   "stand"   red letters standing on a black plinth whose top follows the arc
//   "plaque"  black screen-style plaque, raised red letters, Netflix progress bar, ledge stand
//   "letters" loose chunky letters for a wall, pinboard or shelf
//
// Units mm, Z up. Display datum: centred in X and Y on the text, base at Z = 0.
// Print parts ("part" = anything except "display") sit on Z = 0 in print pose: flat,
// except the one-piece stand parts, which print upright as displayed.
//
// The lettering is a free font (Bebas Neue, SIL OFL) bent like the Netflix wordmark:
// flat top edge, bottom edge on a parabolic arc, so the middle letters are shorter
// than the outer ones. Measured on the Netflix logo: middle letters 13.4 % shorter,
// word 3.70 x its height. Bebas Neue's letter widths match the logo's within about 2 %
// of the letter height; letter_spacing = 1.08 gives the best overlap (83 %) with it.
//
// No experimental features are used: text size is never measured numerically.
// Everything that depends on the text width is derived from the geometry itself
// (bounding bands and resize anchors), so any text, font or size just works.


/* [Text] */
// Text to show
text_string = "NETFLIX";
// Font (Bebas Neue matches the Netflix letter widths best; Google fonts also work on MakerWorld)
font_name = "Bebas Neue"; // font
// Turn the text into capitals
force_caps = true;

/* [Netflix look] */
// How much shorter the middle letters are than the outer ones (0 = straight; Netflix logo = 0.134)
arc_depth = 0.134; // [0:0.002:0.3]
// Letter spacing factor (1 = font default; 1.08 gives the Netflix word proportions with Bebas Neue)
letter_spacing = 1.08; // [0.8:0.01:1.4]
// Extra stroke weight in mm (0 = font as drawn; positive = bolder)
stroke_weight = 0; // [-0.5:0.05:1.5]

/* [Size] */
// Height of the outermost letters (baseline to top) in mm; the width follows from the text
letter_height = 42; // [15:1:150]

/* [Design] */
// Which display to build
design = "stand"; // [stand, plaque, letters]

/* [Stand] */
// Letter thickness, front to back
stand_letter_depth = 8; // [3:0.5:20]
// Plinth height under the outer letters
stand_base_height = 9; // [4:0.5:30]
// Plinth depth, front to back
stand_base_depth = 30; // [10:1:80]
// Plinth overhang past the first and last letter
stand_base_margin = 7; // [0:0.5:30]
// Plinth corner radius (plan view)
stand_base_radius = 5; // [0:0.5:20]
// Chamfer on the plinth's top edges
stand_base_chamfer = 1.2; // [0:0.2:4]
// How far the letter tabs reach into the plinth (two-part build)
stand_tab_depth = 4; // [1:0.5:10]
// Letter position front to back on the plinth (0 = centred, negative = towards the front)
stand_letter_offset = 0; // [-20:0.5:20]
// One-piece upright print: breakaway fins under flat overhangs (arms of E, F, T). Off by default:
// slicer tree supports are proven here, and Bambu Studio warns about model-built supports.
stand_fins = false;
// Fin wall thickness
stand_fin_thickness = 0.8; // [0.4:0.1:2]
// Air gap between fins and letters (about one layer)
stand_fin_gap = 0.25; // [0.1:0.05:0.6]

/* [Plaque] */
// Plaque thickness (black body)
plaque_thickness = 4; // [2:0.2:10]
// Height of the raised letters above the plaque
plaque_relief = 2; // [0.6:0.2:6]
// Border left and right of the text
plaque_margin_x = 12; // [3:0.5:40]
// Border above the text
plaque_margin_top = 11; // [3:0.5:40]
// Border below the text (holds the progress bar and the part hidden in the stand)
plaque_margin_bottom = 22; // [6:0.5:60]
// Distance from the lowest letter to the progress bar's centre line
plaque_bar_gap = 6; // [2:0.5:30]
// Corner radius
plaque_radius = 6; // [0:0.5:30]
// Chamfer on the top edge
plaque_chamfer = 1; // [0:0.2:4]
// Show the Netflix progress bar under the text
plaque_progress_bar = true;
// How far the bar is filled (0..1)
plaque_progress = 0.62; // [0:0.01:1]
// Bar thickness (in the plaque plane)
plaque_bar_width = 2.4; // [1:0.1:6]
// Depth of the bar's track groove
plaque_track_depth = 0.6; // [0.2:0.2:2]
// Height of the red bar fill above the plaque face
plaque_bar_relief = 1; // [0.2:0.2:4]
// Single-colour version: how deep the separate red letters and bar sit in their pockets
plaque_inlay_depth = 1.2; // [0.6:0.2:3]
// Lean of the plaque in its stand (degrees back from vertical)
plaque_tilt = 12; // [0:1:30]
// Stand length as a fraction of the plaque width
plaque_stand_fraction = 0.72; // [0.3:0.01:1]
// Stand height
plaque_stand_height = 12; // [6:0.5:40]
// Stand depth front to back
plaque_stand_depth = 36; // [15:1:80]

/* [Loose letters] */
// Letter thickness
letters_depth = 10; // [3:0.5:30]
// Front edge chamfer (0 = none)
letters_chamfer = 1.2; // [0:0.2:4]
// Red face thickness in the two-colour version (the rest is the black body)
letters_face_depth = 3; // [0.6:0.2:10]
// Flatten each letter's bottom so it can stand on a shelf
letters_flat_bottom = false;
// Back: "none" or a "recess" for tape, putty or magnet sheet
letters_mount = "none"; // [none, recess]
// Recess depth and wall thickness
letters_recess_depth = 3; // [1:0.5:10]
letters_recess_wall = 2.4; // [1.2:0.2:6]

/* [Fit and print] */
// Clearance per side for push-fit joints
clearance = 0.15; // [0:0.05:0.5]
// Layer height the stepped chamfers are drawn for
layer_height = 0.2; // [0.08:0.02:0.32]

/* [Colours] */
color_letters = "#E50914"; // color
color_base    = "#141414"; // color
color_track   = "#5A5A5A"; // color

/* [MakerWorld] */
// Stand plates in MakerWorld's 3MF: two parts to press together (any printer), or one upright multi-colour piece (AMS)
makerworld_stand = "two parts"; // [two parts, one piece]

/* [Hidden] */
// What to output: "display" = coloured preview; the rest are print parts laid flat
part = "display";
// Which letter for the single-letter parts (0 = first)
letter_index = 0;
// Turn print parts about Z (e.g. 90 so tall letters run along a bed-slinger's Y axis)
print_rotate = 0;
desktop_output = false;  // false in the MakerWorld edition
$fn = 48;
eps = 0.01;          // overlap for coplanar booleans
BIG = 1e4;           // "infinity" for bounding bands
NORM_W = 100;        // normalised word width used while bending
// Bend resolution: enough vertical strips that the step between neighbours along the
// bottom edge stays under bend_step (mm). Straight text (arc_depth = 0) needs none.
bend_step = 0.1;
warp_strips = min(800, max(60, ceil(4.2 * letter_height * arc_depth / bend_step)));
H = letter_height;

txt = force_caps ? upper(text_string) : text_string;
n_letters = len(txt);

assert(n_letters > 0, "text_string is empty");
assert(arc_depth >= 0 && arc_depth < 0.5, "arc_depth must be in [0, 0.5)");
assert(letter_index >= 0 && letter_index < n_letters, "letter_index is past the end of the text");
assert(stand_tab_depth < stand_base_height, "stand_tab_depth must be less than stand_base_height");
assert(stand_base_height < 0.85 * letter_height && plaque_margin_bottom < 0.85 * letter_height, "base height and plaque bottom margin must stay under 0.85 x letter_height");
assert(letters_face_depth < letters_depth, "letters_face_depth must be less than letters_depth");
assert(plaque_inlay_depth < plaque_thickness - 0.8, "plaque_inlay_depth must leave at least 0.8 mm of plaque under the pockets");
assert(plaque_margin_bottom - plaque_bar_gap - plaque_bar_width > (plaque_stand_height - 3) / cos(plaque_tilt) + 1,
       "progress bar would be hidden by the stand: raise plaque_margin_bottom or lower plaque_stand_height");
echo(str("Text '", txt, "', font ", font_name, ", outer letters ", H, " mm, design ", design, ", part ", part));

// ------------------------------------------------------------------ functions

function upper(s) = chr([for (c = s) let(o = ord(c))
    (o >= 97 && o <= 122) || (o >= 224 && o <= 254 && o != 247) ? o - 32 : o]);

function prefix(s, n) = n <= 0 ? "" : chr([for (k = [0 : n - 1]) ord(s[k])]);

// Vertical scale at normalised position u in [-1, 1]: 1 at the ends, 1 - arc_depth in the middle.
function arc_scale(u) = let(v = max(-1, min(1, u))) 1 - arc_depth * (1 - v * v);

// ------------------------------------------------------------------ 2D helpers

// Bounding rectangle of 2D children.
module bbox2d() {
    intersection() {
        hull() { translate([0,  BIG]) children(); translate([0, -BIG]) children(); }
        hull() { translate([ BIG, 0]) children(); translate([-BIG, 0]) children(); }
    }
}

// Vertical band covering the children's x-range.
module xband2d() {
    hull() { translate([0, BIG]) children(); translate([0, -BIG]) children(); }
}
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

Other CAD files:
netflix-lettering/print-files/colour-swap/a1-mini/netflix-stand-colour-swap-a1-mini.3mf
netflix-lettering/print-files/single-colour/a1-mini/netflix-plaque-single-colour-a1-mini.3mf
netflix-lettering/print-files/ams/a1-mini/netflix-stand-ams-a1-mini.3mf
netflix-lettering/print-files/ams/a2l-combo/serier-plaque-ams-a2l-combo.3mf
netflix-lettering/print-files/ams/a1-mini/serier-letters-ams-a1-mini.3mf
netflix-lettering/print-files/ams/a2l-combo/netflix-letters-ams-a2l-combo.3mf
netflix-lettering/print-files/colour-swap/a1-mini/netflix-letters-colour-swap-a1-mini.3mf
netflix-lettering/print-files/colour-swap/a1-mini/serier-stand-colour-swap-a1-mini.3mf
netflix-lettering/print-files/single-colour/a1-mini/serier-letters-single-colour-a1-mini.3mf
netflix-lettering/print-files/single-colour/a1-mini/serier-stand-single-colour-a1-mini.3mf

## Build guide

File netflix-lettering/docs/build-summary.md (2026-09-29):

# Build summary

Generated by `tools/build.py`. Every project was sliced with the stock Bambu Studio
profiles (0.20 mm Standard, Bambu PLA Matte, textured PEI plate) and checked: real
printer start G-code, the intended filament on every plate, pauses exactly where the
colour changes, and no stray sliver pieces in any part.

Times and weights are Bambu Studio's estimates. On pause plates the weight is the
total for both colours (black up to the pause, red after it).

| Project | Printer | Plates | Print time | Filament |
|---|---|---|---|---|
| [`ams/a1-mini/netflix-stand-ams-a1-mini.3mf`](../print-files/ams/a1-mini/netflix-stand-ams-a1-mini.3mf) | Bambu Lab A1 mini, with AMS lite | 1 | 1 h 52 min | red 24 g, black 29 g |
| [`ams/a1-mini/netflix-plaque-ams-a1-mini.3mf`](../print-files/ams/a1-mini/netflix-plaque-ams-a1-mini.3mf) | Bambu Lab A1 mini, with AMS lite | 1 | 1 h 18 min | red 7 g, black 48 g, grey 1 g |
| [`ams/a1-mini/netflix-letters-ams-a1-mini.3mf`](../print-files/ams/a1-mini/netflix-letters-ams-a1-mini.3mf) | Bambu Lab A1 mini, with AMS lite | 1 | 1 h 24 min | red 18 g, black 29 g |
| [`ams/a2l-combo/netflix-stand-ams-a2l-combo.3mf`](../print-files/ams/a2l-combo/netflix-stand-ams-a2l-combo.3mf) | Bambu Lab A2L Combo, with AMS lite | 1 | 5 h 00 min | red 78 g, black 107 g |
| [`ams/a2l-combo/netflix-plaque-ams-a2l-combo.3mf`](../print-files/ams/a2l-combo/netflix-plaque-ams-a2l-combo.3mf) | Bambu Lab A2L Combo, with AMS lite | 1 | 3 h 34 min | red 22 g, black 159 g, grey 1 g |
| [`ams/a2l-combo/netflix-letters-ams-a2l-combo.3mf`](../print-files/ams/a2l-combo/netflix-letters-ams-a2l-combo.3mf) | Bambu Lab A2L Combo, with AMS lite | 1 | 3 h 16 min | red 51 g, black 84 g |
| [`single-colour/a1-mini/netflix-stand-single-colour-a1-mini.3mf`](../print-files/single-colour/a1-mini/netflix-stand-single-colour-a1-mini.3mf) | Bambu Lab A1 mini, no AMS, one colour per plate | 2 | 1 h 24 min | red 17 g, black 28 g |
| [`single-colour/a1-mini/netflix-plaque-single-colour-a1-mini.3mf`](../print-files/single-colour/a1-mini/netflix-plaque-single-colour-a1-mini.3mf) | Bambu Lab A1 mini, no AMS, one colour per plate | 2 | 1 h 31 min | red 7 g, black 50 g |
| [`single-colour/a1-mini/netflix-letters-single-colour-a1-mini.3mf`](../print-files/single-colour/a1-mini/netflix-letters-single-colour-a1-mini.3mf) | Bambu Lab A1 mini, no AMS, one colour per plate | 2 | 1 h 25 min | red 47 g |
| [`colour-swap/a1-mini/netflix-stand-colour-swap-a1-mini.3mf`](../print-files/colour-swap/a1-mini/netflix-stand-colour-swap-a1-mini.3mf) | Bambu Lab A1 mini, no AMS, manual colour swap | 2 | 1 h 24 min | red 17 g, black 28 g |
| [`colour-swap/a1-mini/netflix-plaque-colour-swap-a1-mini.3mf`](../print-files/colour-swap/a1-mini/netflix-plaque-colour-swap-a1-mini.3mf) | Bambu Lab A1 mini, no AMS, manual colour swap | 2 | 1 h 14 min | 52 g black + red (manual swap) |
| [`colour-swap/a1-mini/netflix-letters-colour-swap-a1-mini.3mf`](../print-files/colour-swap/a1-mini/netflix-letters-colour-swap-a1-mini.3mf) | Bambu Lab A1 mini, no AMS, manual colour swap | 2 | 1 h 25 min | 47 g black + red (manual swap) |
| [`ams/a1-mini/serier-stand-ams-a1-mini.3mf`](../print-files/ams/a1-mini/serier-stand-ams-a1-mini.3mf) | Bambu Lab A1 mini, with AMS lite | 1 | 1 h 49 min | red 24 g, black 25 g |
| [`ams/a1-mini/serier-plaque-ams-a1-mini.3mf`](../print-files/ams/a1-mini/serier-plaque-ams-a1-mini.3mf) | Bambu Lab A1 mini, with AMS lite | 1 | 1 h 11 min | red 7 g, black 41 g, grey 1 g |
| [`ams/a1-mini/serier-letters-ams-a1-mini.3mf`](../print-files/ams/a1-mini/serier-letters-ams-a1-mini.3mf) | Bambu Lab A1 mini, with AMS lite | 1 | 1 h 27 min | red 17 g, black 27 g |
| [`ams/a2l-combo/serier-stand-ams-a2l-combo.3mf`](../print-files/ams/a2l-combo/serier-stand-ams-a2l-combo.3mf) | Bambu Lab A2L Combo, with AMS lite | 1 | 4 h 55 min | red 77 g, black 94 g |
| [`ams/a2l-combo/serier-plaque-ams-a2l-combo.3mf`](../print-files/ams/a2l-combo/serier-plaque-ams-a2l-combo.3mf) | Bambu Lab A2L Combo, with AMS lite | 1 | 3 h 11 min | red 21 g, black 137 g, grey 1 g |
| [`ams/a2l-combo/serier-letters-ams-a2l-combo.3mf`](../print-files/ams/a2l-combo/serier-letters-ams-a2l-combo.3mf) | Bambu Lab A2L Combo, with AMS lite | 1 | 3 h 25 min | red 48 g, black 79 g |
| [`single-colour/a1-mini/serier-stand-single-colour-a1-mini.3mf`](../print-files/single-colour/a1-mini/serier-stand-single-colour-a1-mini.3mf) | Bambu Lab A1 mini, no AMS, one colour per plate | 2 | 1 h 22 min | red 16 g, black 24 g |
| [`single-colour/a1-mini/serier-plaque-single-colour-a1-mini.3mf`](../print-files/single-colour/a1-mini/serier-plaque-single-colour-a1-mini.3mf) | Bambu Lab A1 mini, no AMS, one colour per plate | 2 | 1 h 22 min | red 6 g, black 44 g |
| [`single-colour/a1-mini/serier-letters-single-colour-a1-mini.3mf`](../print-files/single-colour/a1-mini/serier-letters-single-colour-a1-mini.3mf) | Bambu Lab A1 mini, no AMS, one colour per plate | 2 | 1 h 28 min | red 44 g |
| [`colour-swap/a1-mini/serier-stand-colour-swap-a1-mini.3mf`](../print-files/colour-swap/a1-mini/serier-stand-colour-swap-a1-mini.3mf) | Bambu Lab A1 mini, no AMS, manual colour swap | 2 | 1 h 22 min | red 16 g, black 24 g |
| [`colour-swap/a1-mini/serier-plaque-colour-swap-a1-mini.3mf`](../print-files/colour-swap/a1-mini/serier-plaque-colour-swap-a1-mini.3mf) | Bambu Lab A1 mini, no AMS, manual colour swap | 2 | 1 h 05 min | 45 g black + red (manual swap) |
| [`colour-swap/a1-mini/serier-letters-colour-swap-a1-mini.3mf`](../print-files/colour-swap/a1-mini/serier-letters-colour-swap-a1-mini.3mf) | Bambu Lab A1 mini, no AMS, manual colour swap | 2 | 1 h 28 min | 44 g black + red (manual swap) |

Plates of one project can run on different printers at the same time,
so the wall-clock time with two A1 minis is the longest plate, not the total.

## Plates

### ams/a1-mini/netflix-stand-ams-a1-mini.3mf

- Printed upright in one piece; the AMS switches between red and black.
- Tree supports hold up the arms of E, F and T; they snap off from the hidden undersides. (The model can build breakaway fins instead, `stand_fins = true`, but Bambu Studio flags model-built supports as a floating cantilever, so the files use its own.)
- The word runs along the bed's Y axis so the thin letters are stiff against the moving bed.

- Plate 1: **1/1 One piece - red letters on black plinth (tree supports)**: 112 min, 29 AMS changes

### ams/a1-mini/netflix-plaque-ams-a1-mini.3mf

- One print: the AMS does the black plaque, red letters and bar, and the grey bar track.
- Slide the plaque into the stand's leaning slot.

- Plate 1: **1/1 Plaque (black, red, grey) + stand (black)**: 78 min, 17 AMS changes

### ams/a1-mini/netflix-letters-ams-a1-mini.3mf

- Two-tone letters: the AMS changes from black to red once per plate.
- Hang them with the paper template in templates/ so the arc lines up.

- Plate 1: **Letters N E T F L I X - black body, red face**: 84 min, 1 AMS changes

### ams/a2l-combo/netflix-stand-ams-a2l-combo.3mf

- Printed upright in one piece; the AMS switches between red and black.
- Tree supports hold up the arms of E, F and T; they snap off from the hidden undersides. (The model can build breakaway fins instead, `stand_fins = true`, but Bambu Studio flags model-built supports as a floating cantilever, so the files use its own.)
- The word runs along the bed's Y axis so the thin letters are stiff against the moving bed.

- Plate 1: **1/1 One piece - red letters on black plinth (tree supports)**: 300 min, 51 AMS changes

### ams/a2l-combo/netflix-plaque-ams-a2l-combo.3mf

- One print: the AMS does the black plaque, red letters and bar, and the grey bar track.
- Slide the plaque into the stand's leaning slot.

- Plate 1: **1/1 Plaque (black, red, grey) + stand (black)**: 214 min, 23 AMS changes

### ams/a2l-combo/netflix-letters-ams-a2l-combo.3mf

- Two-tone letters: the AMS changes from black to red once per plate.
- Hang them with the paper template in templates/ so the arc lines up.

- Plate 1: **Letters N E T F L I X - black body, red face**: 196 min, 1 AMS changes

### single-colour/a1-mini/netflix-stand-single-colour-a1-mini.3mf

- Plate 1 in red, plate 2 in black: on two printers at once, or one after the other.
- Push the letters' tabs into the plinth pockets (press fit, a drop of glue makes it permanent).

- Plate 1: **1/2 Letters - red - face down (printer A)**: 38 min
- Plate 2: **2/2 Plinth - black (printer B)**: 46 min

### single-colour/a1-mini/netflix-plaque-single-colour-a1-mini.3mf

- Plate 1 in red: the letters and the progress bar's fill as separate pieces, printed face down.
- Plate 2 in black: the plaque with matching pockets, and its stand.
- Press each red piece into its pocket (0.15 mm clearance per side; a drop of glue makes it permanent). Slide the plaque into the stand's leaning slot.

- Plate 1: **1/2 Red pieces - letters and bar, face down (printer A)**: 17 min
- Plate 2: **2/2 Plaque with pockets + stand - black (printer B)**: 74 min

### single-colour/a1-mini/netflix-letters-single-colour-a1-mini.3mf

- All-red letters, split over two plates so two printers can share the work.
- Hang them with the paper template in templates/ so the arc lines up.

- Plate 1: **1/2 Letters N E T F - red**: 51 min
- Plate 2: **2/2 Letters L I X - red**: 34 min

### colour-swap/a1-mini/netflix-stand-colour-swap-a1-mini.3mf

- Plate 1 in red, plate 2 in black: on two printers at once, or one after the other.
- Push the letters' tabs into the plinth pockets (press fit, a drop of glue makes it permanent).
- No pause needed: each plate is one colour, so on one printer just change the spool between plates. (The arched plinth has no single layer where black could end, so a one-piece swap isn't possible.)

- Plate 1: **1/2 Letters - red - face down (printer A)**: 38 min
- Plate 2: **2/2 Plinth - black (printer B)**: 46 min

### colour-swap/a1-mini/netflix-plaque-colour-swap-a1-mini.3mf

- Plate 1 starts in black and pauses at 4.2 mm: unload black, load red, resume.
- The progress bar's track stays as a black groove; the filled part and the letters come out red.
- Slide the plaque into the stand's leaning slot.

- Plate 1: **1/2 Plaque - start black, PAUSE at 4.2 mm, load red (printer A)**: 47 min, pause at 4.2 mm
- Plate 2: **2/2 Stand - black (printer B)**: 27 min

### colour-swap/a1-mini/netflix-letters-colour-swap-a1-mini.3mf

- Each plate starts in black and pauses at 7.2 mm: swap to red and resume, for black letters with a red face.
- The letters are split over two plates so two printers can share the work.
- Hang them with the paper template in templates/ so the arc lines up.

- Plate 1: **1/2 Letters N E T F - start black, PAUSE at 7.2 mm, load red**: 51 min, pause at 7.2 mm
- Plate 2: **2/2 Letters L I X - start black, PAUSE at 7.2 mm, load red**: 34 min, pause at 7.2 mm

### ams/a1-mini/serier-stand-ams-a1-mini.3mf

- Printed upright in one piece; the AMS switches between red and black.
- Tree supports hold up the arms of E, F and T; they snap off from the hidden undersides. (The model can build breakaway fins instead, `stand_fins = true`, but Bambu Studio flags model-built supports as a floating cantilever, so the files use its own.)
- The word runs along the bed's Y axis so the thin letters are stiff against the moving bed.

- Plate 1: **1/1 One piece - red letters on black plinth (tree supports)**: 109 min, 29 AMS changes

### ams/a1-mini/serier-plaque-ams-a1-mini.3mf

- One print: the AMS does the black plaque, red letters and bar, and the grey bar track.
- Slide the plaque into the stand's leaning slot.

- Plate 1: **1/1 Plaque (black, red, grey) + stand (black)**: 71 min, 17 AMS changes

### ams/a1-mini/serier-letters-ams-a1-mini.3mf

- Two-tone letters: the AMS changes from black to red once per plate.
- Hang them with the paper template in templates/ so the arc lines up.

- Plate 1: **Letters S E R I E R - black body, red face**: 87 min, 1 AMS changes

### ams/a2l-combo/serier-stand-ams-a2l-combo.3mf

- Printed upright in one piece; the AMS switches between red and black.
- Tree supports hold up the arms of E, F and T; they snap off from the hidden undersides. (The model can build breakaway fins instead, `stand_fins = true`, but Bambu Studio flags model-built supports as a floating cantilever, so the files use its own.)
- The word runs along the bed's Y axis so the thin letters are stiff against the moving bed.

- Plate 1: **1/1 One piece - red letters on black plinth (tree supports)**: 295 min, 51 AMS changes

### ams/a2l-combo/serier-plaque-ams-a2l-combo.3mf

- One print: the AMS does the black plaque, red letters and bar, and the grey bar track.
- Slide the plaque into the stand's leaning slot.

- Plate 1: **1/1 Plaque (black, red, grey) + stand (black)**: 191 min, 23 AMS changes

### ams/a2l-combo/serier-letters-ams-a2l-combo.3mf

- Two-tone letters: the AMS changes from black to red once per plate.
- Hang them with the paper template in templates/ so the arc lines up.

- Plate 1: **Letters S E R I E R - black body, red face**: 205 min, 1 AMS changes

### single-colour/a1-mini/serier-stand-single-colour-a1-mini.3mf

- Plate 1 in red, plate 2 in black: on two printers at once, or one after the other.
- Push the letters' tabs into the plinth pockets (press fit, a drop of glue makes it permanent).

- Plate 1: **1/2 Letters - red - face down (printer A)**: 40 min
- Plate 2: **2/2 Plinth - black (printer B)**: 42 min

### single-colour/a1-mini/serier-plaque-single-colour-a1-mini.3mf

- Plate 1 in red: the letters and the progress bar's fill as separate pieces, printed face down.
- Plate 2 in black: the plaque with matching pockets, and its stand.
- Press each red piece into its pocket (0.15 mm clearance per side; a drop of glue makes it permanent). Slide the plaque into the stand's leaning slot.

- Plate 1: **1/2 Red pieces - letters and bar, face down (printer A)**: 17 min
- Plate 2: **2/2 Plaque with pockets + stand - black (printer B)**: 65 min

### single-colour/a1-mini/serier-letters-single-colour-a1-mini.3mf

- All-red letters, split over two plates so two printers can share the work.
- Hang them with the paper template in templates/ so the arc lines up.

- Plate 1: **1/2 Letters S E R - red**: 48 min
- Plate 2: **2/2 Letters I E R - red**: 40 min

### colour-swap/a1-mini/serier-stand-colour-swap-a1-mini.3mf

- Plate 1 in red, plate 2 in black: on two printers at once, or one after the other.
- Push the letters' tabs into the plinth pockets (press fit, a drop of glue makes it permanent).
- No pause needed: each plate is one colour, so on one printer just change the spool between plates. (The arched plinth has no single layer where black could end, so a one-piece swap isn't possible.)

- Plate 1: **1/2 Letters - red - face down (printer A)**: 40 min
- Plate 2: **2/2 Plinth - black (printer B)**: 42 min

### colour-swap/a1-mini/serier-plaque-colour-swap-a1-mini.3mf

- Plate 1 starts in black and pauses at 4.2 mm: unload black, load red, resume.
- The progress bar's track stays as a black groove; the filled part and the letters come out red.
- Slide the plaque into the stand's leaning slot.

- Plate 1: **1/2 Plaque - start black, PAUSE at 4.2 mm, load red (printer A)**: 42 min, pause at 4.2 mm
- Plate 2: **2/2 Stand - black (printer B)**: 23 min

### colour-swap/a1-mini/serier-letters-colour-swap-a1-mini.3mf

- Each plate starts in black and pauses at 7.2 mm: swap to red and resume, for black letters with a red face.
- The letters are split over two plates so two printers can share the work.
- Hang them with the paper template in templates/ so the arc lines up.

- Plate 1: **1/2 Letters S E R - start black, PAUSE at 7.2 mm, load red**: 48 min, pause at 7.2 mm
- Plate 2: **2/2 Letters I E R - start black, PAUSE at 7.2 mm, load red**: 40 min, pause at 7.2 mm

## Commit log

2026-09-29 feat(netflix-lettering): add Netflix-style lettering display (#1)
    * feat(netflix-lettering): add parametric Netflix-style lettering model
    Bebas Neue (bundled with Anton and League Gothic, all SIL OFL) bent like
    the Netflix wordmark: flat top edge, bottom on a parabolic arc with the
    middle letters 13.4 % shorter. Three designs share the lettering core:
    an arched-plinth stand, a screen plaque with a progress bar, and loose
    two-tone wall letters. Uses no experimental OpenSCAD features, so it
    runs in the stock Customizer and on MakerWorld.
    * build(netflix-lettering): add Bambu Studio project builder
    tools/build.py exports every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
    [netflix-lettering-makerworld.scad, netflix-lettering.scad, netflix-letters-ams-a1-mini.3mf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]
2026-10-09 ci: add the edbfi core CI (#4)
    * ci: add the edbfi core CI
    prek.toml becomes .pre-commit-config.yaml (normalised per edbfi-ci design/prek.md), plus ci.yml, pr-policy.yml, dependabot.yml and immortality.yml from the edbfi-ci Content templates. The builtin hoo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
    * ci: add the Dependabot auto-merge workflow
    Added after the main ruleset exists (edbfi-ci design/auto-merge.md rule 2).
    ---------
2026-10-21 chore: drop references to edbfi-ci's deleted design docs (#7)
    edbfi-ci#93 deleted design/, STATE.md and DECISIONS.md. Comments and docs that cited them now say what they need to themselves, and the copied template comments match the current templates.
2026-10-27 refactor: rename netflix-lettering to streaming-lettering (#10)
    Drop the Netflix naming from the design: rename the folder, model and
    MakerWorld edition, remove the NETFLIX word variant and its print files,
    renders, plate previews and templates, and reword the docs and comments
    to refer to a generic streaming wordmark. SERIER is now the default and
    only word. Model geometry and setting names are unchanged.
2026-10-27 feat(streaming-lettering): hide seams, cut supports and colour changes in every print file (#11)
    * feat(streaming-lettering): optimise print files and add a Linux toolchain
    Print files, measured by slicing every project:
    - paint seams onto each part's hidden side (stand letters' seams were on
    their fronts; now 99 % sit on the backs)
    - one-piece stand: Tree Strong supports (A2L: 317 instead of 362 min,
    13 instead of 28 g of support)
    - AMS plaque: stand on its own plate (A2L: 8 instead of 23 colour changes)
    - loose letters: printed face down with lightning infill (A2L set 89
    instead of 126 g)
    - prime tower off on purpose (the CLI dropped it by accident before)
    - every part a closed soli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
2026-10-27 docs: cut doc duplication and stale numbers, add CLAUDE.md rules against doc bloat (#12)
    * docs: tighten documentation and add CLAUDE.md documentation rules
    Fix stale or wrong claims found in review (render and plate times, strip
    count, cleanup offsets, loose-letter face depth, colour-change count,
    'nothing is compiled'), drop text that restates code or other docs, give
    each topic one home, and add repo rules against documentation bloat.
    * docs: address council review findings
    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
2026-10-27 feat(streaming-lettering)!: print every stand without supports (#13)
    * feat(streaming-lettering)!: print every stand without supports
    The AMS stand now uses the two-part stand (face-down letters, plinth with
    pockets), on the A1 mini and the A2L. Upright in one piece, the arms of E,
    F and T needed Bambu tree supports, and the arched plinth cost a colour
    change on every shared layer.
    Removes the tree-supported one-piece variant, the home-made stand_fins,
    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
2026-10-28 build(streaming-lettering): fail the build on slicer supports and unsupported overhangs (#14)
    Forces enable_support off in the process preset, fails any plate whose
    G-code has a support feature, and widens check_overhangs to every variant
    of Bambu Studio's "re-orient the object or enable support generation"
    warning (floating regions, floating cantilever, large overhangs); it only
    caught the first two.
2026-10-28 docs: make support-free printing a repo rule, with Support Fins as the only fallback (#15)
    * docs: add support-free printing rules to CLAUDE.md
    Every part prints without supports by design; Support Fins, run with bun,
    is the only allowed fallback; the build's support checks stay strict.
    * docs: make the CLAUDE.md support checks a requirement and the DfAM skill optional
    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
2026-10-28 build(streaming-lettering): slice every print file with Bambu PLA Basic (#16)
    * build(streaming-lettering): slice with Bambu PLA Basic instead of PLA Matte
    Switch the A1 mini and A2L filament presets to Bambu PLA Basic, use its
    1.26 g/cm3 density for purge grams, and regenerate the print files and
    build summary.
    * docs(streaming-lettering): mark the plinth-arch layer test as done in matte PLA
    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
2026-10-28 feat(streaming-lettering): pin the lettering to a pinboard, framed or see-through (#17)
    * feat(streaming-lettering): add pinboard frames, with and without a backing panel
    Two new designs hold the loose letters on a cloth pinboard: "frame" glues
    them into pockets in a black backing panel with a border, and "open-frame"
    cuts the panel back to two rails hidden behind the letters' top and bottom
    strokes, so the board shows through. Both print back down in sections that
    dovetail together, sized by the build to fit the bed, and pin to the board
    through holes in the border.
    The prime-tower corner is now kept free only on AMS plates that change
    colour, so a frame section fits the A1 mini.
    Signed-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
2026-11-02 chore: share one build toolchain and set agents up for text-to-cad and OpenSCAD (#20)
    * chore: share the build toolchain and set up agent tooling
    Make AGENTS.md the agent instructions (CLAUDE.md links to it), with a map of
    where each topic lives and when to model in build123d with text-to-cad or in
    OpenSCAD. Move the Docker toolchain to tools/docker/ for every design, and add
    tools/openscad so the pinned openscad-mcp server renders with the same OpenSCAD
    from Claude Code, Codex and OpenCode.
    * fix: pin text-to-cad, say which agent has which tool, cap CPUs only when asked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
2026-11-02 feat(q6a-fan-stand): hold an 80 mm Noctua over the Q6A's Armor Case, header free (#21)
    * build(docker): add build123d to the shared toolchain
    Pin build123d 0.13.0 and its dependencies by hash in a virtualenv that
    comes first on PATH. Rebuild streaming-lettering with the new image.
    * feat(q6a-fan-stand): add a fan stand for the Radxa Dragon Q6A in its Armor Case
    A Noctua NF-A8 blows down onto the case's fins from a hood that plugs
    into a base the case sits in: tool-free, every port and the 40-pin header
    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
2026-11-03 feat(streaming-lettering): add a BOOKFLIX stand, printed diagonally to keep SERIER's size (#22)
    * feat(streaming-lettering): add a BOOKFLIX stand
    Build BOOKFLIX as a stand only, at SERIER's letter height. Its plinth and
    letters are longer than either bed, so the build now turns any part too
    long for the bed 45° to lie diagonally, with its seam painting.
    * docs(streaming-lettering): point variant_makers at takes() for its text filter
    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
2026-11-03 feat(streaming-lettering): add a BOOKFLIX open frame for the pinboard, at SERIER's tested letter size (#23)
    feat(streaming-lettering): add a BOOKFLIX open frame
    Build BOOKFLIX as an open frame as well as a stand, at the letter size of
    the test-printed SERIER open frame: 75 mm letters on the A1 mini, 120 mm on
    the A2L. The A1 mini frame prints in 3 sections, the A2L one in 2.
2026-11-03 fix(streaming-lettering): stop Bambu Studio's invalid-name error when opening projects (#24)
    fix(streaming-lettering): name plates without slashes so Bambu Studio opens projects cleanly
    Bambu Studio rejects <>:/\|?*" in names and showed an error on opening any
    project whose plates were named "1/2 ..." or "Frame 1/3 ...". Number them
    "1 of 2 - ..." instead, and fail the build on any plate or object name
    Bambu Studio would reject.
2026-11-04 feat: publish print files as one GitHub release per design, starting with the fan stand (#25)
    * feat: publish print files as per-design GitHub releases, starting with q6a-fan-stand
    Print files and STEP exports leave git: each design's build writes unsliced Bambu Studio
    projects to build/release/, and tools/release.sh publishes them from main as the design's
    rolling <design>-latest release, after checking the rebuild matches what main committed.
    The README documents the naming scheme for files and plates.
    q6a-fan-stand moves first: one project per printer (a1-mini, a2l) with the fit test as
    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
2026-11-04 feat(streaming-lettering): publish 8 print files as one release instead of 28 in git (#26)
    * feat(streaming-lettering): publish print files as the streaming-lettering-latest release
    Build one unsliced project per product and printer, streaming-lettering-{stand,plaque,frame,open-frame}-{a1-mini,a2l}.3mf,
    in build/release/ for tools/release.sh, and stop committing print-files/ and plate images.
    Drop the colour-swap and single-colour sets and the pause machinery: MakerWorld bans
    pause-based colour-swap profiles and single-colour copies of multi-colour ones. The plaque
    keeps its inlay version for printers without an AMS. Rename a2l-combo to a2l.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
2026-11-05 fix: kill a runaway CAD export inside its container instead of the whole machine (#27)
    * fix: kill a runaway CAD export inside its container instead of the whole machine
    Cap the build and openscad MCP containers' memory with no swap and make
    them the first thing the kernel kills. Give every OpenSCAD run a time
    limit, stop all exports at the first failure with the part's name, and
    fit --jobs to the memory cap. AGENTS.md says what to do when a part is
    killed: it is a geometry bug, not a cap to raise.
    * fix: forward OPENSCAD_TIMEOUT, stop the fan stand at its first failure in time, and say only OpenSCAD runs are time-limited
    Si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
2026-11-05 feat(streaming-lettering): add Populære nu, Serier and Nyheder sub-headings in small capitals for under BOOKFLIX (#28)
    * feat(streaming-lettering): add Populære nu, Serier and Nyheder sub-headings in small capitals for under BOOKFLIX
    Loose letters, straight, about half BOOKFLIX's height, with only the first
    letter full height. White on red, all white and all red, as plates in one
    project per printer. small_caps in the .scad sets the first letter and the
    rest at the first letter's advance without measuring the text, and keeps
    small capitals straight.
    * fix(streaming-lettering): keep the sub-heading templates' line clear of r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
2026-11-05 fix(streaming-lettering): drop the sub-headings' one-colour plates, which MakerWorld bans as copies (#29)
    The all-white and all-red plates were one-colour copies of the white-on-red
    letters, which MakerWorld's profile rules (section 6.5) don't allow, in the project
    or as a profile of their own. Setting both filaments to one colour prints
    the white-on-red plates in that colour instead.
2026-11-05 feat(streaming-lettering): add pin-tab sub-headings that pin to a fabric pinboard without holes through the letters (#30)
    * feat(streaming-lettering): add pin-tab sub-headings for pinning to a fabric pinboard
    Each sub-heading word gets a second plate of its letters with a thin red tab
    behind the top and bottom of every letter, holed for a dressmaker's pin, so
    no hole goes through a letter (letters_mount = "pins"). The tabs sit on the
    capitals' lines and centre on each letter's edge ink; the letters print face
    up on them, so they need no supports and stay in the body's colour.
    * fix(streaming-lettering): guard the pin-tab asse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
